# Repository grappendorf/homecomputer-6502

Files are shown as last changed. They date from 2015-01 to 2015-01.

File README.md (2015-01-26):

HomeComputer 6502
=================

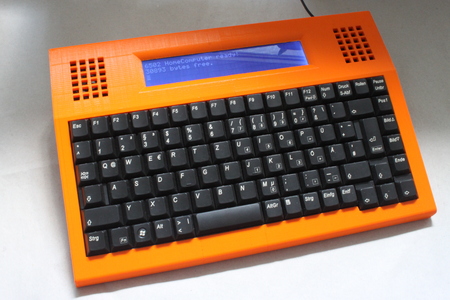
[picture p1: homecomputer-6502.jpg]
HomeComputer 6502


This is my attempt to build a simple, mobile microcomputer system with an 8-bit MOS 6502 CPU that was used in many popular
home computers of the 1970s and 1980s like the Commodore 64 or the Apple II.

The idea was to design a computer like the C64, almost only using parts that were available when this computer was
manufactured.

The hardware is designed with [Eagle](http://www.cadsoft.de/eagle-pcb-design-software/).

The software is written in 6502 assembler and C, with the help of the [CC65 compiler/assembler](http://cc65.github.io/cc65/).

The case is designed with [Autodesk 123D Design](http://www.123dapp.com/design).

Documentation of this project can be found on my website: http://www.grappendorf.net/projects/6502-home-computer

This repositiory contains the following files:

* eagle - Eagle schematic and board files
* schematics - PDF schematics
* case - 123D/STL design files for the case
* firmware - Minimal BASIC interpreter written with CC65,  different versions of the firmware during the development process
* terminal -  Small ruby script for loading/saving of BASIC programs, example BASIC programs

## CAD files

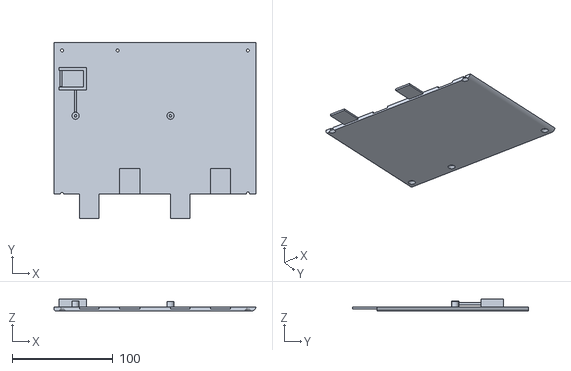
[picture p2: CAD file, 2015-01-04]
case/stl/parts/HomeComputer 6502 Bottom Right.stl
200.0 x 174.5 x 12.0

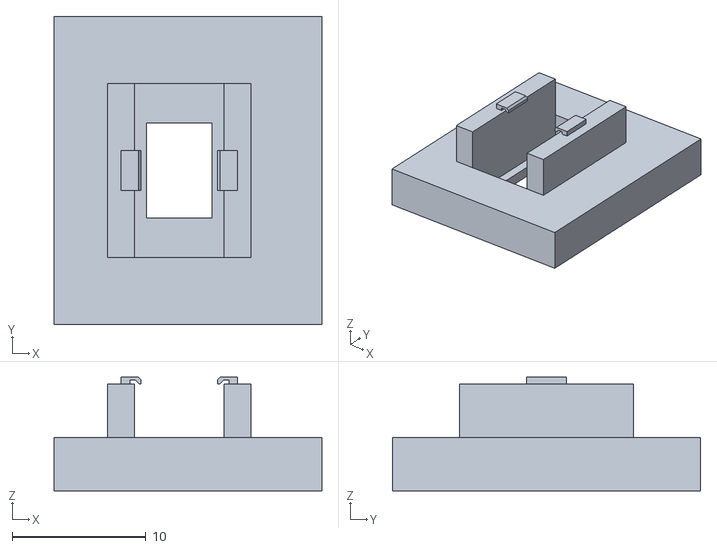
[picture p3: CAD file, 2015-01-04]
case/stl/Switch.stl
20.0 x 23.0 x 8.50

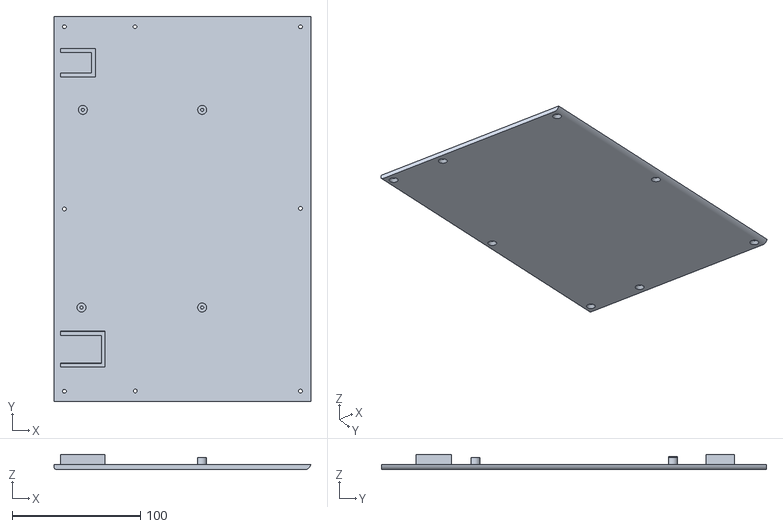
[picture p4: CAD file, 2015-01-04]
case/stl/HomeComputer 6502 Bottom.stl
200.0 x 300.0 x 12.0

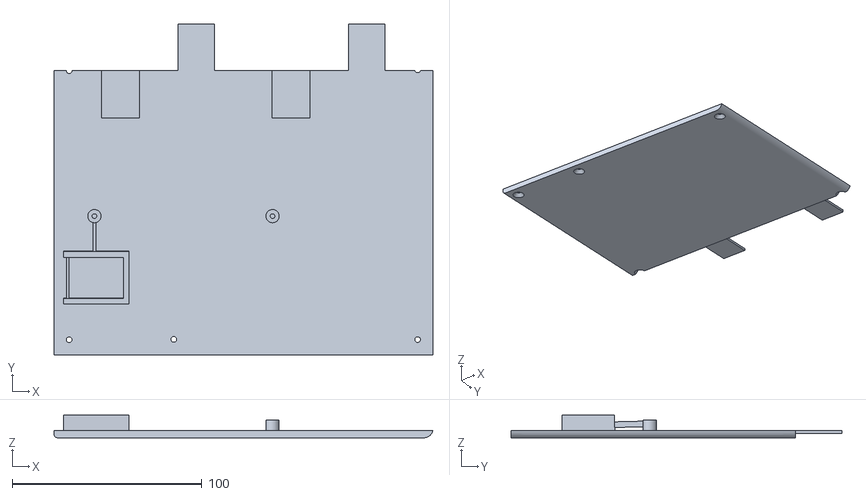
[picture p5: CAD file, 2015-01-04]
case/stl/parts/HomeComputer 6502 Bottom Left.stl
200.0 x 174.6 x 12.0

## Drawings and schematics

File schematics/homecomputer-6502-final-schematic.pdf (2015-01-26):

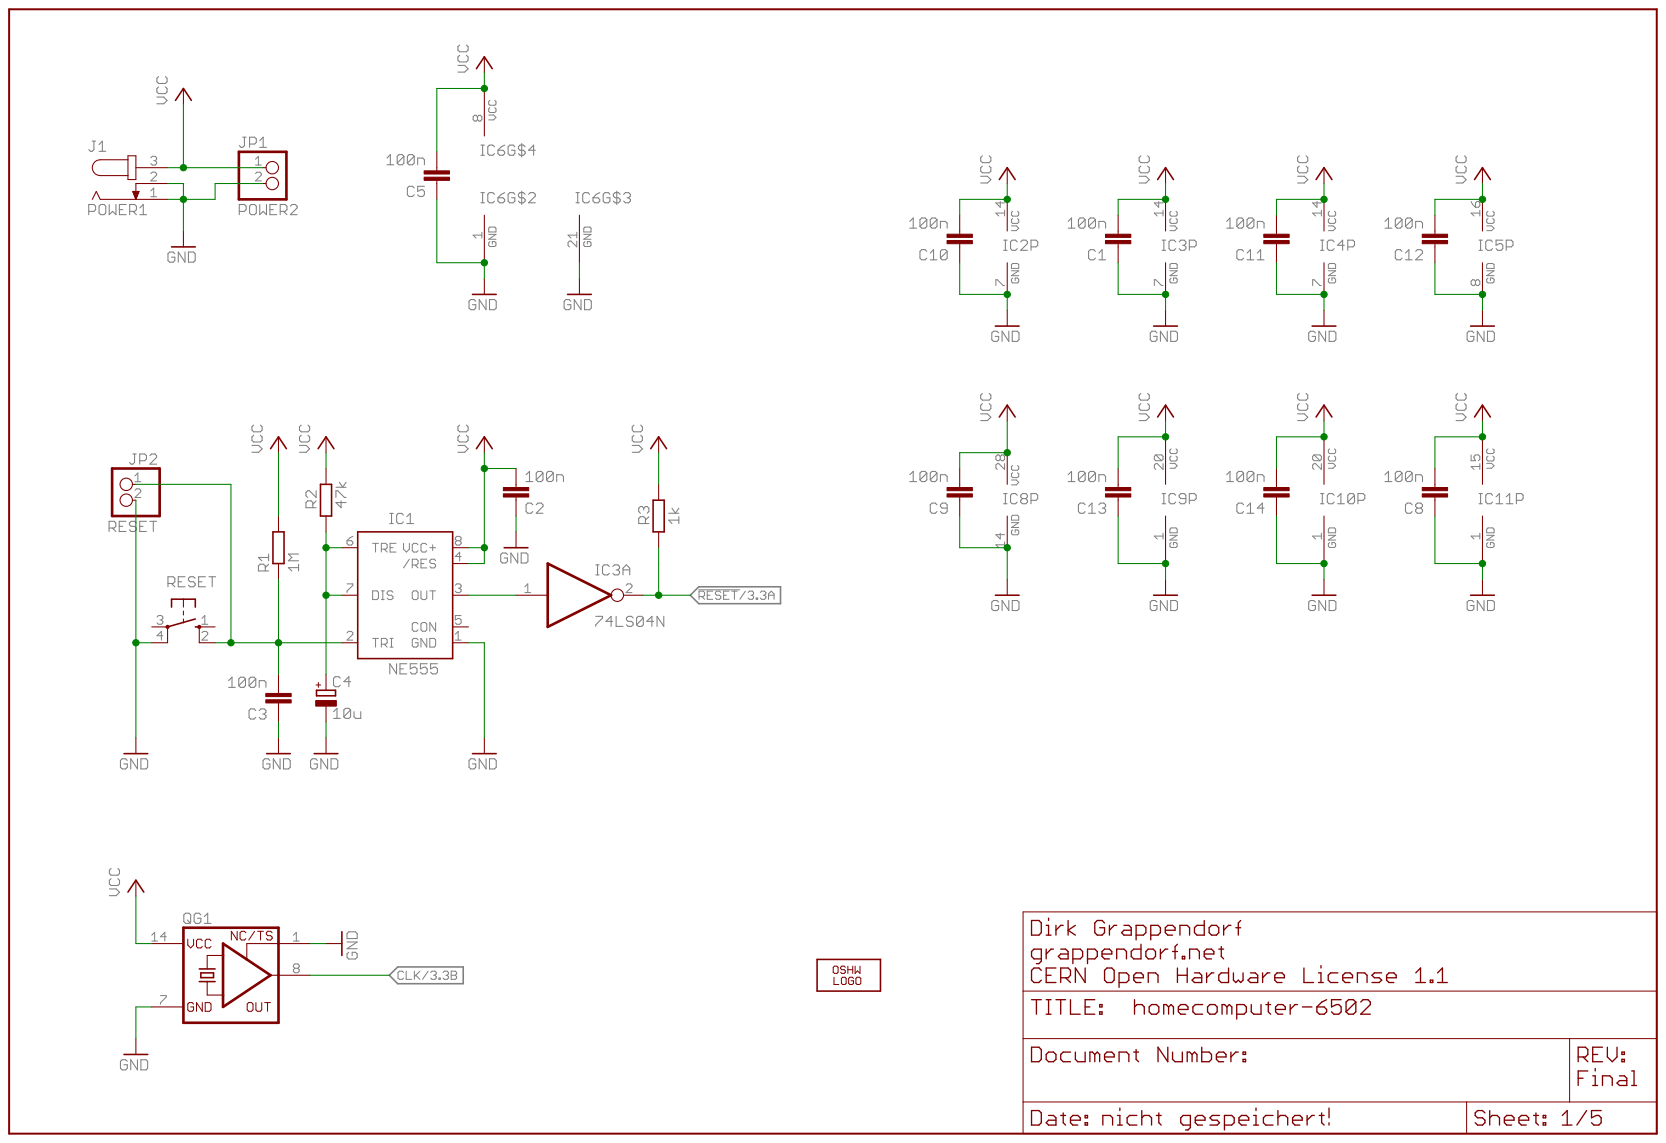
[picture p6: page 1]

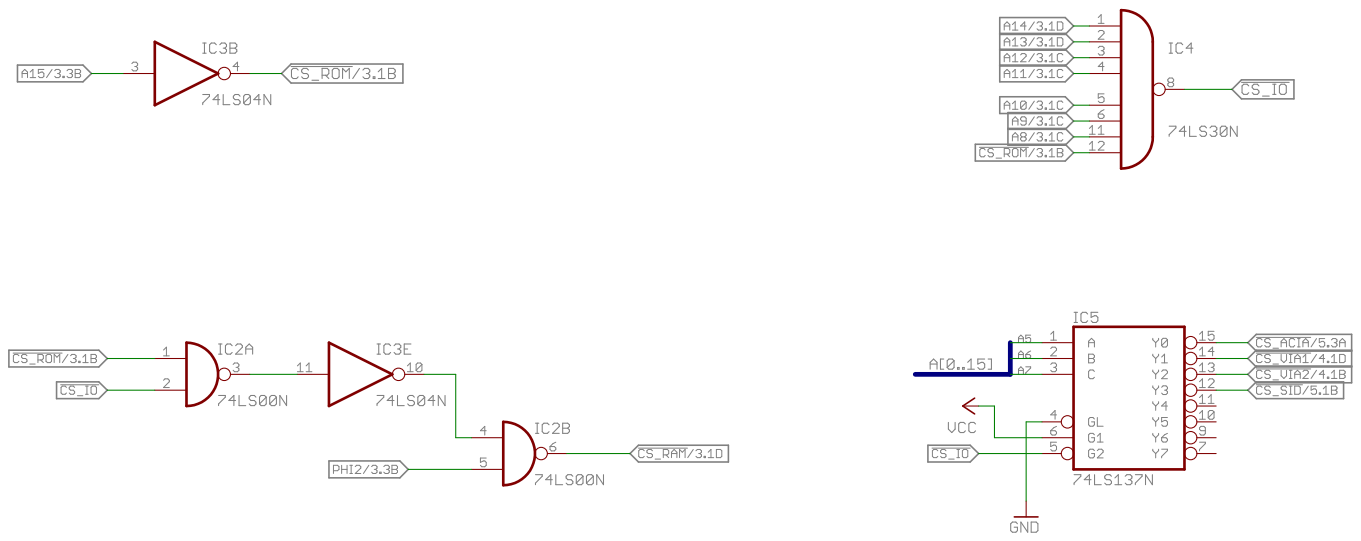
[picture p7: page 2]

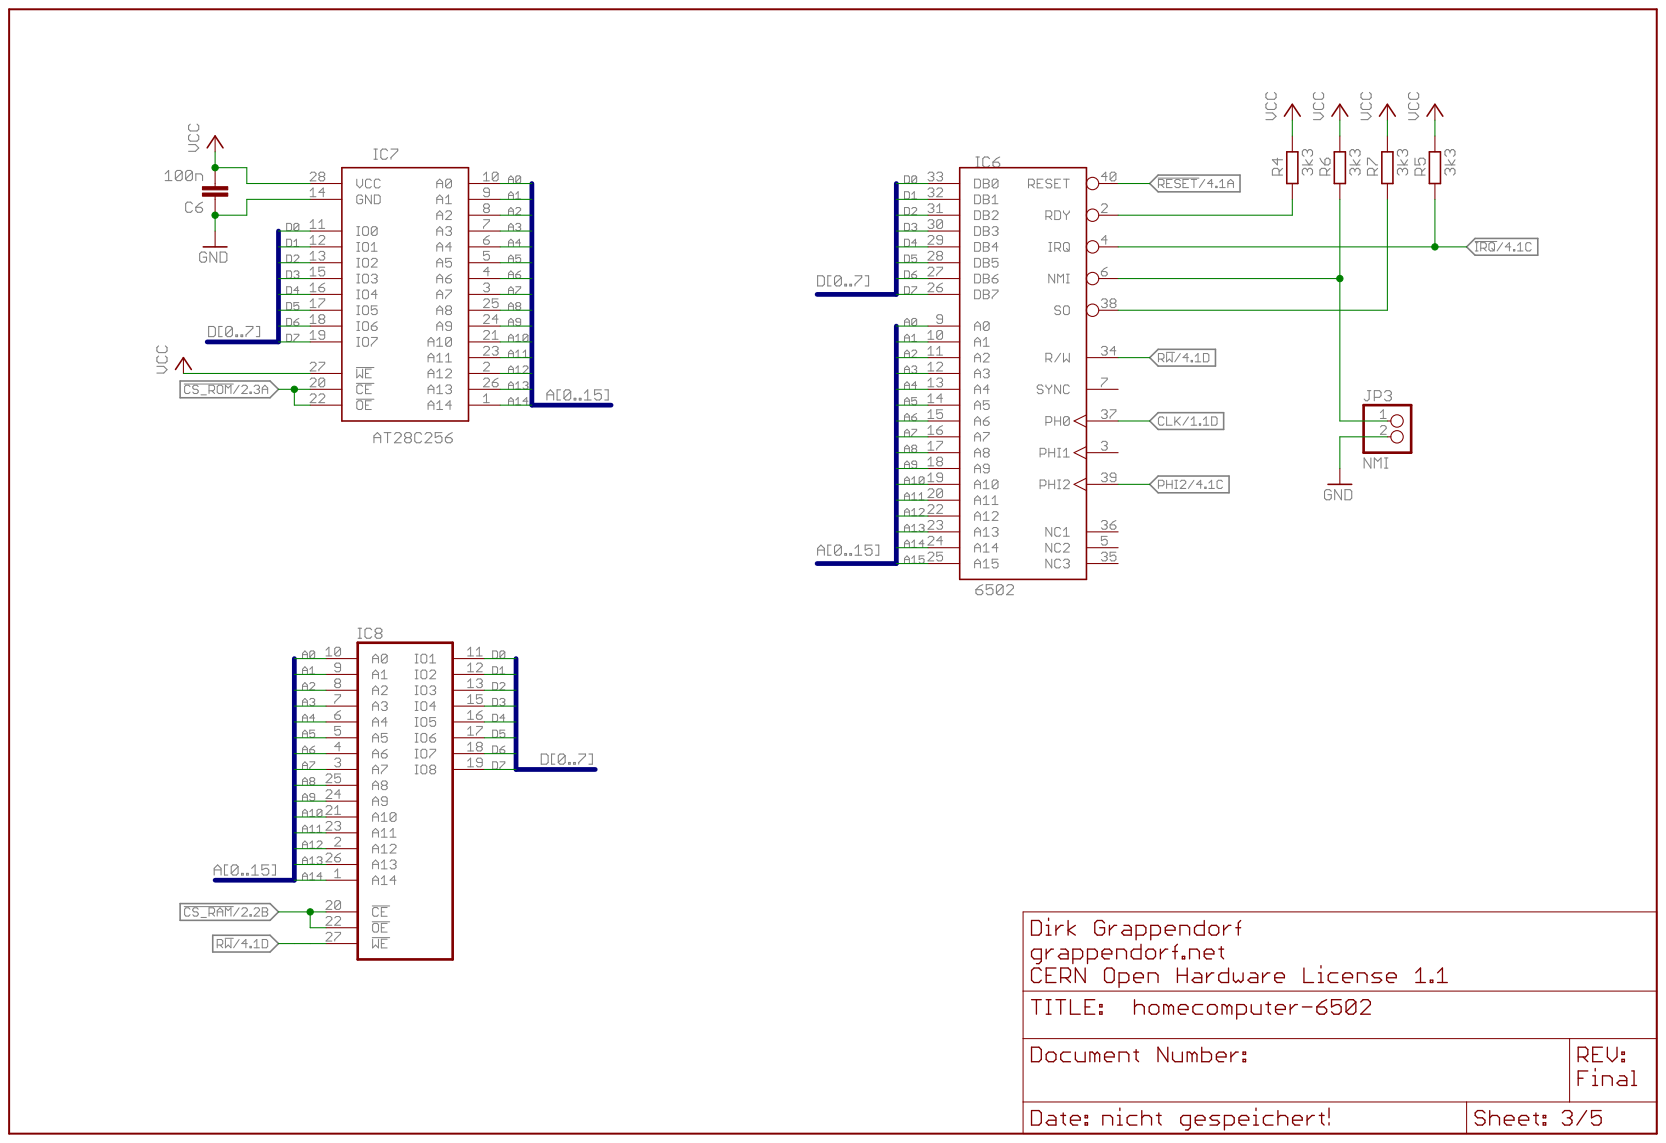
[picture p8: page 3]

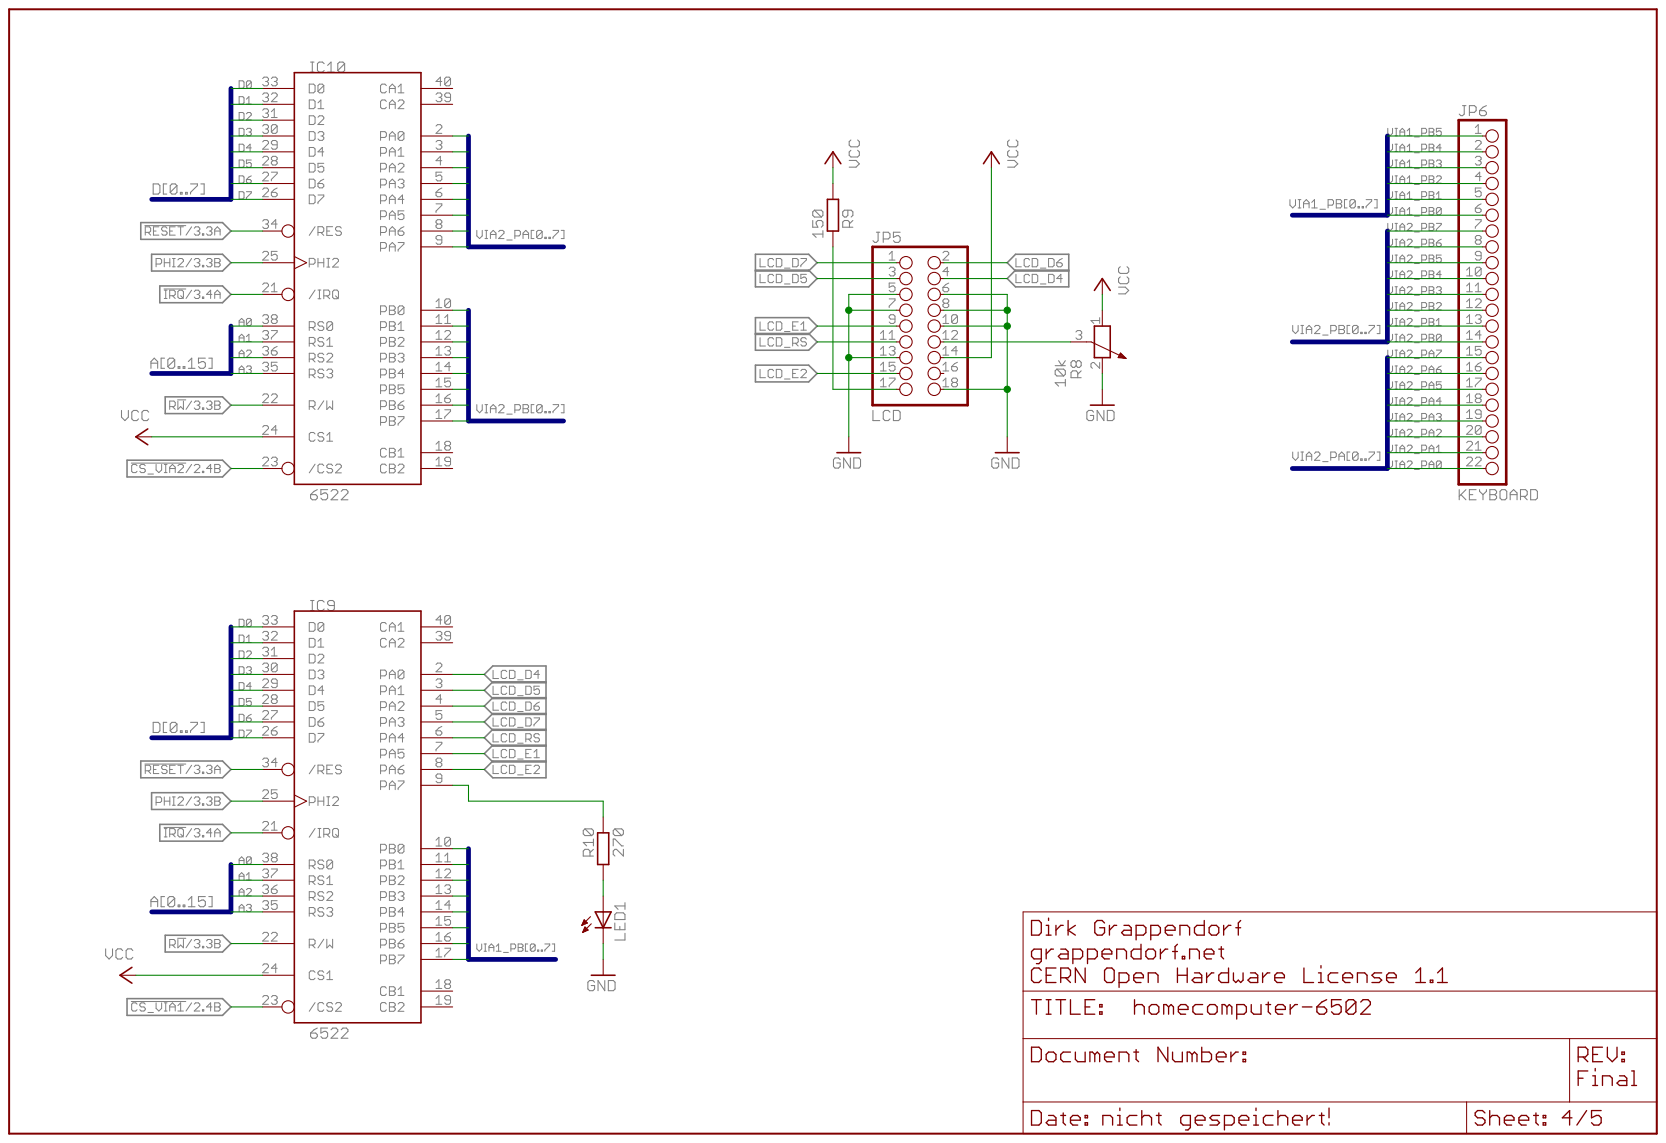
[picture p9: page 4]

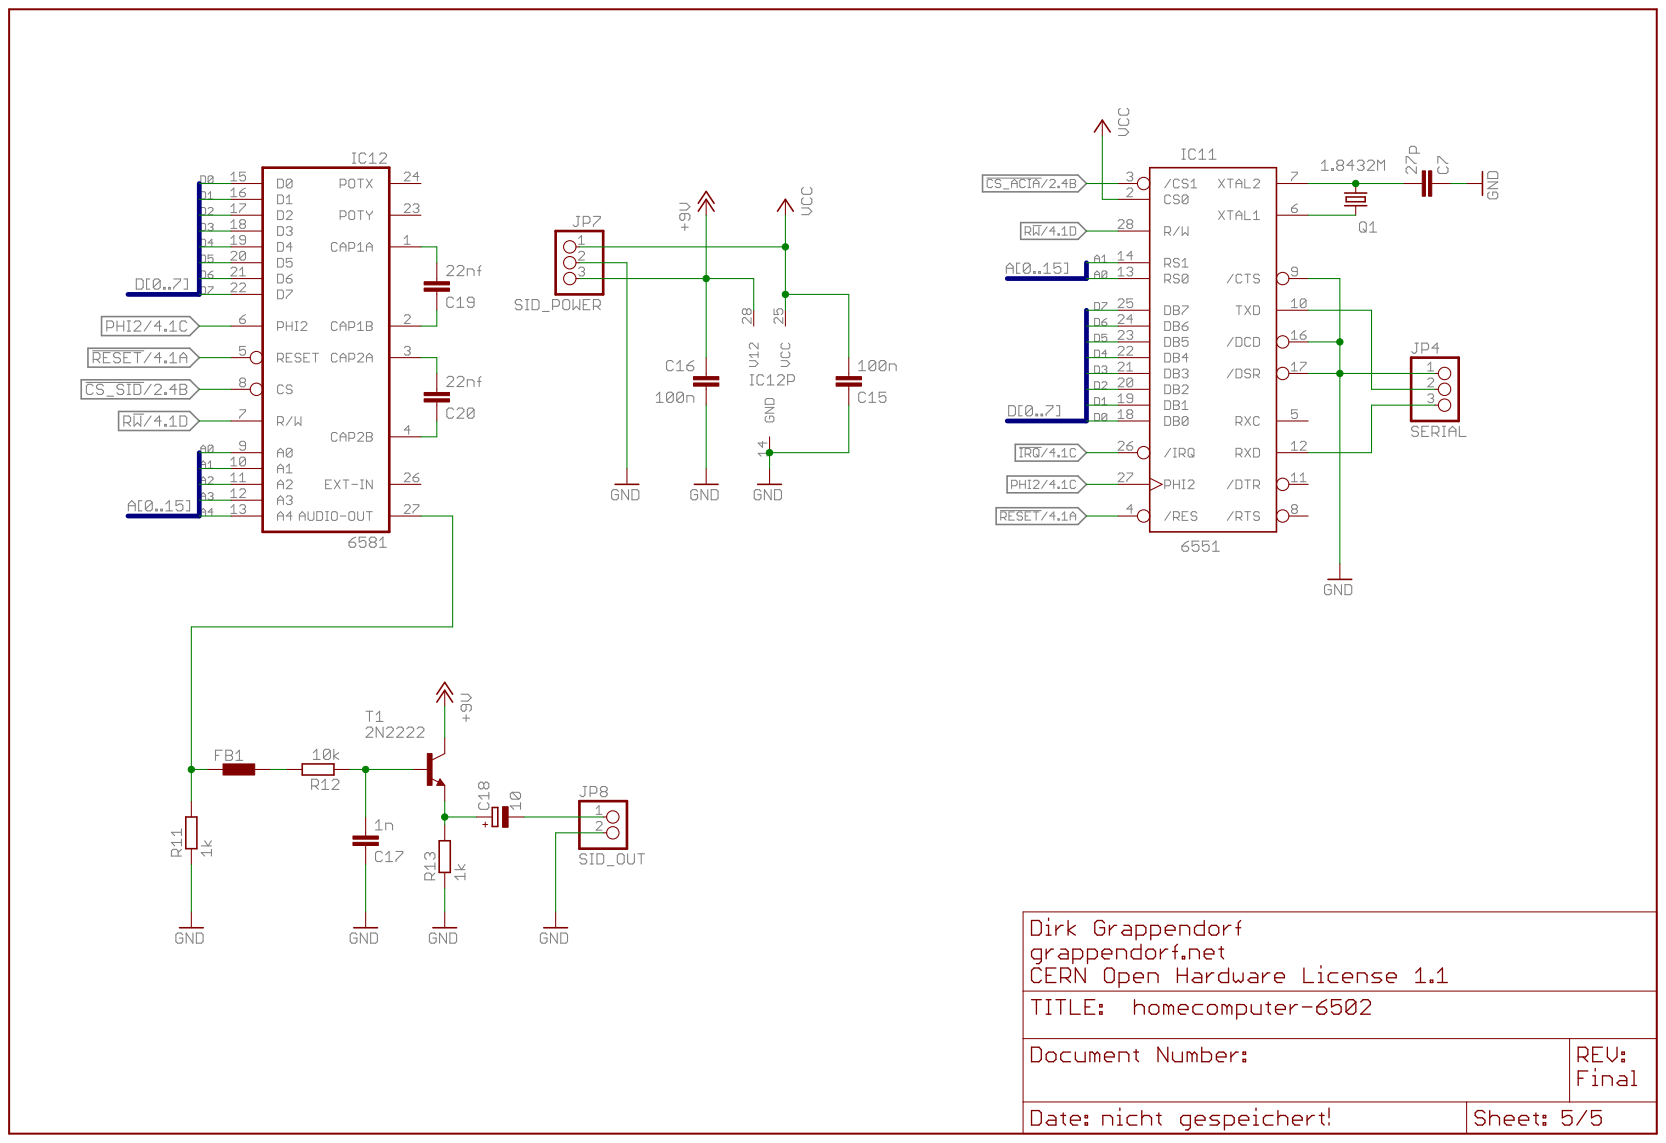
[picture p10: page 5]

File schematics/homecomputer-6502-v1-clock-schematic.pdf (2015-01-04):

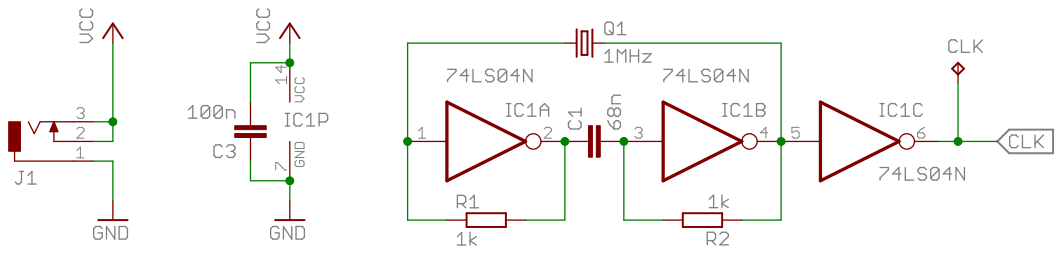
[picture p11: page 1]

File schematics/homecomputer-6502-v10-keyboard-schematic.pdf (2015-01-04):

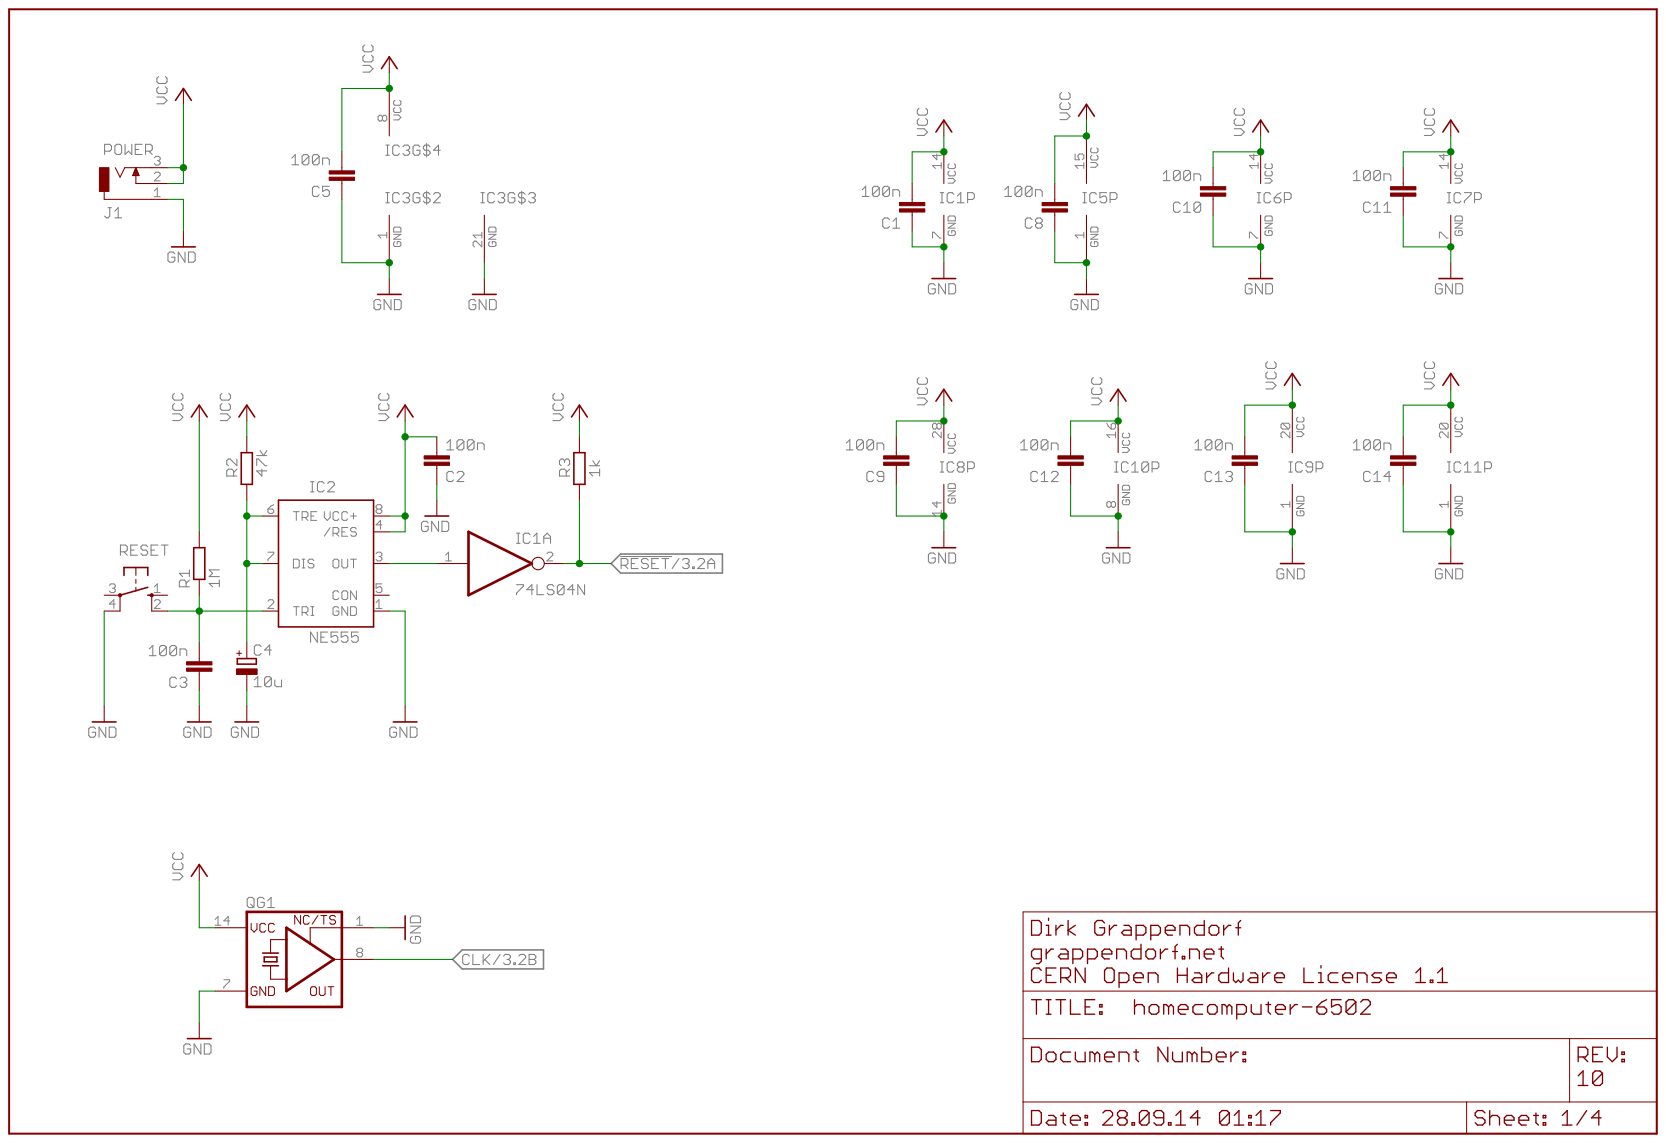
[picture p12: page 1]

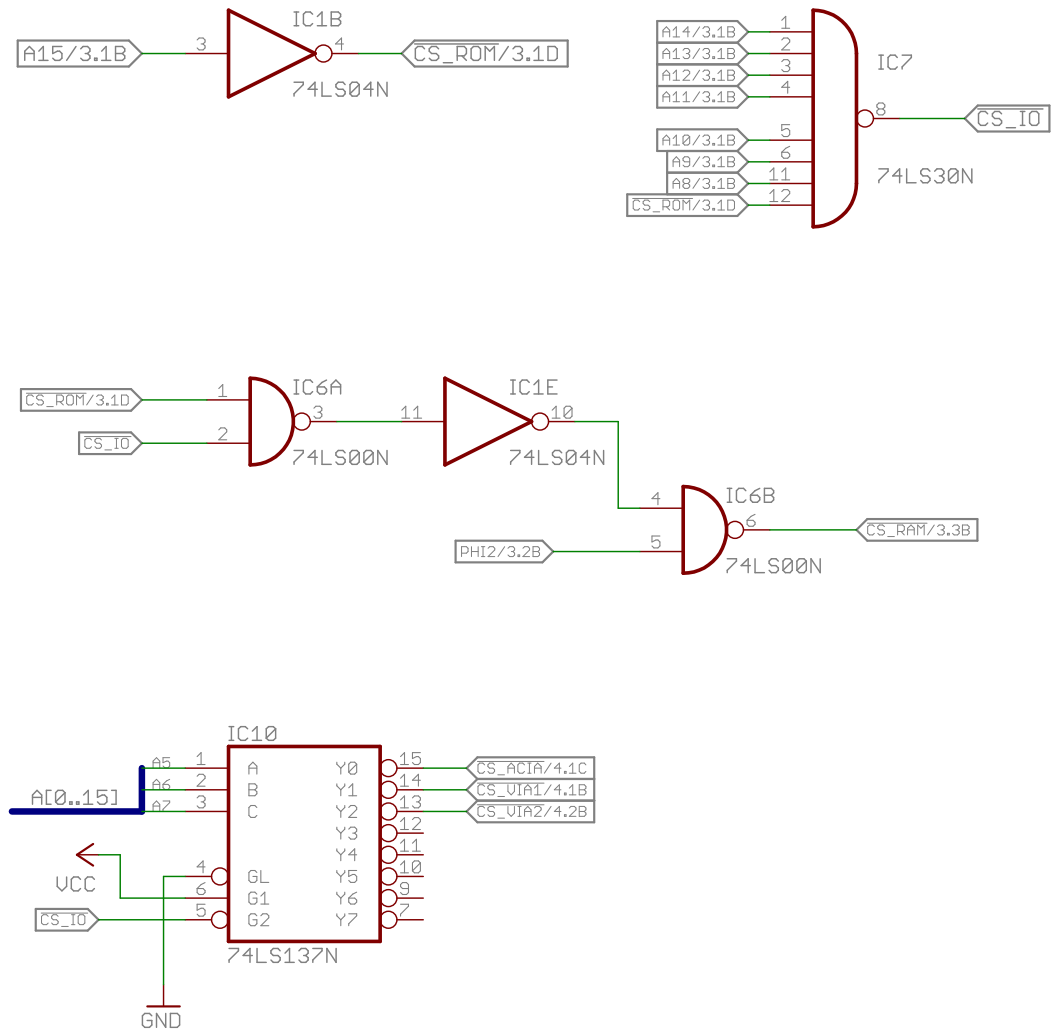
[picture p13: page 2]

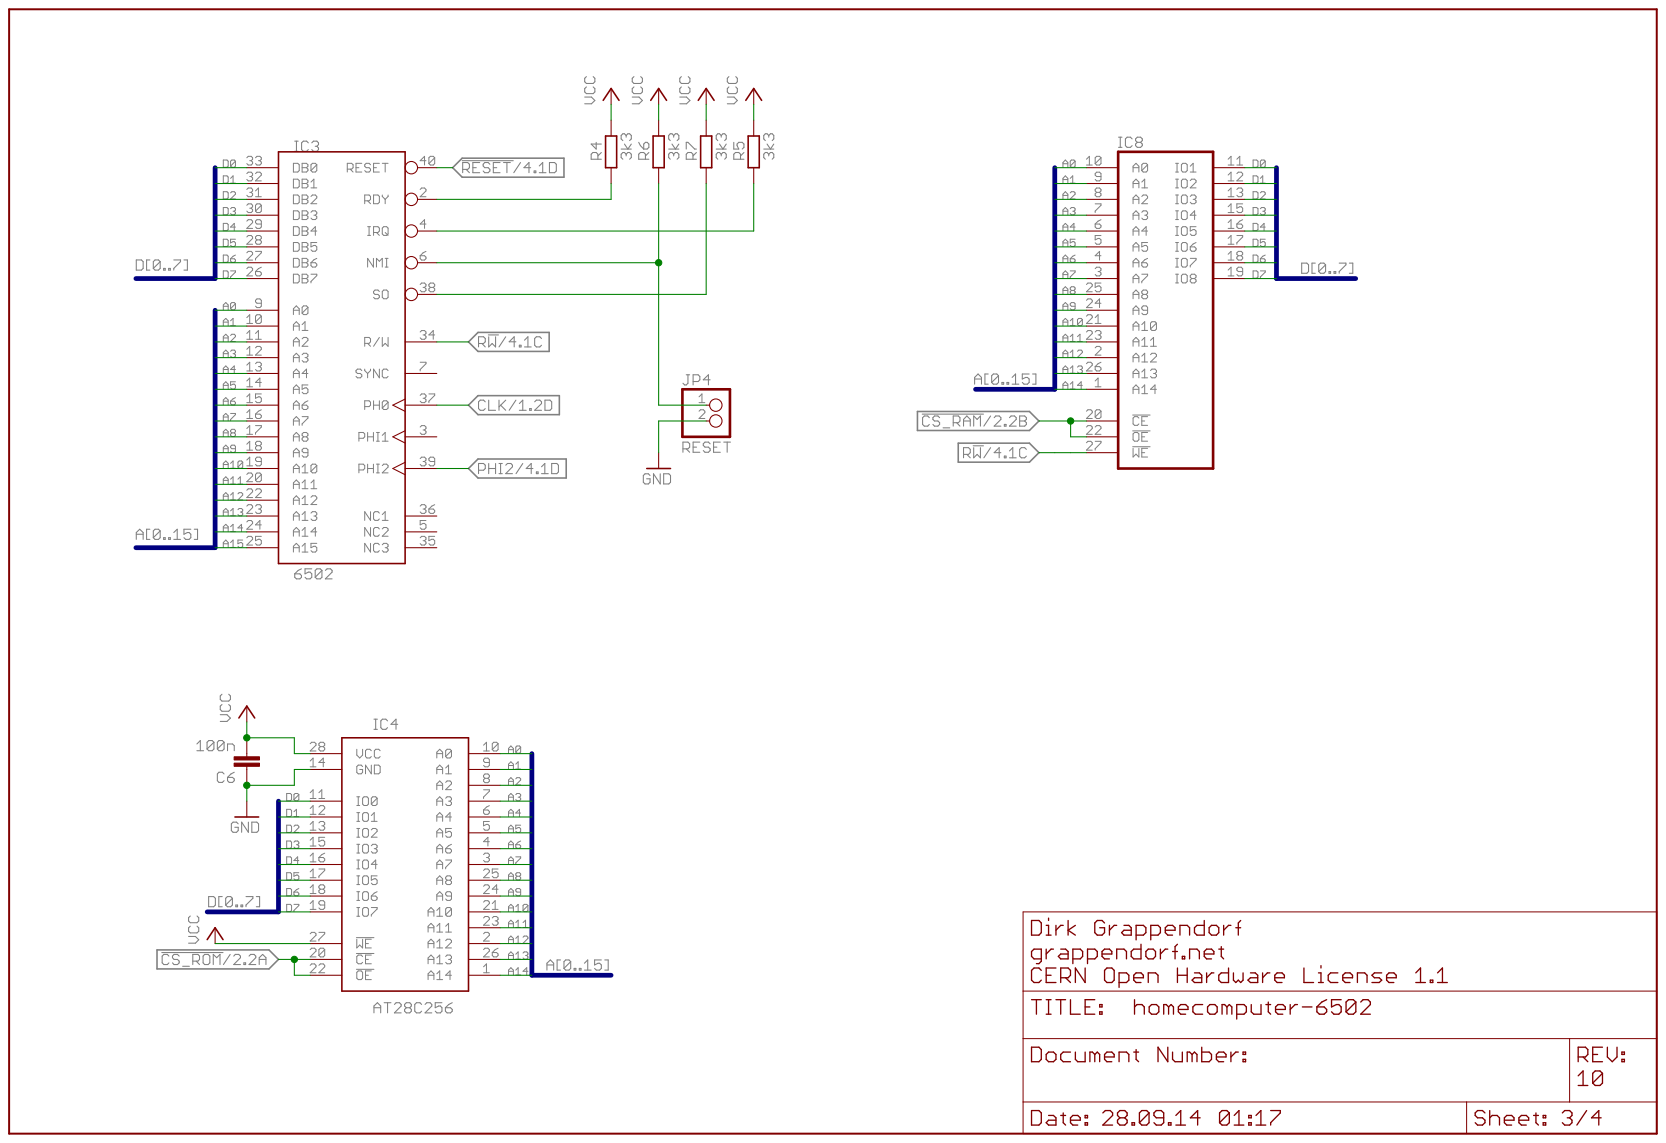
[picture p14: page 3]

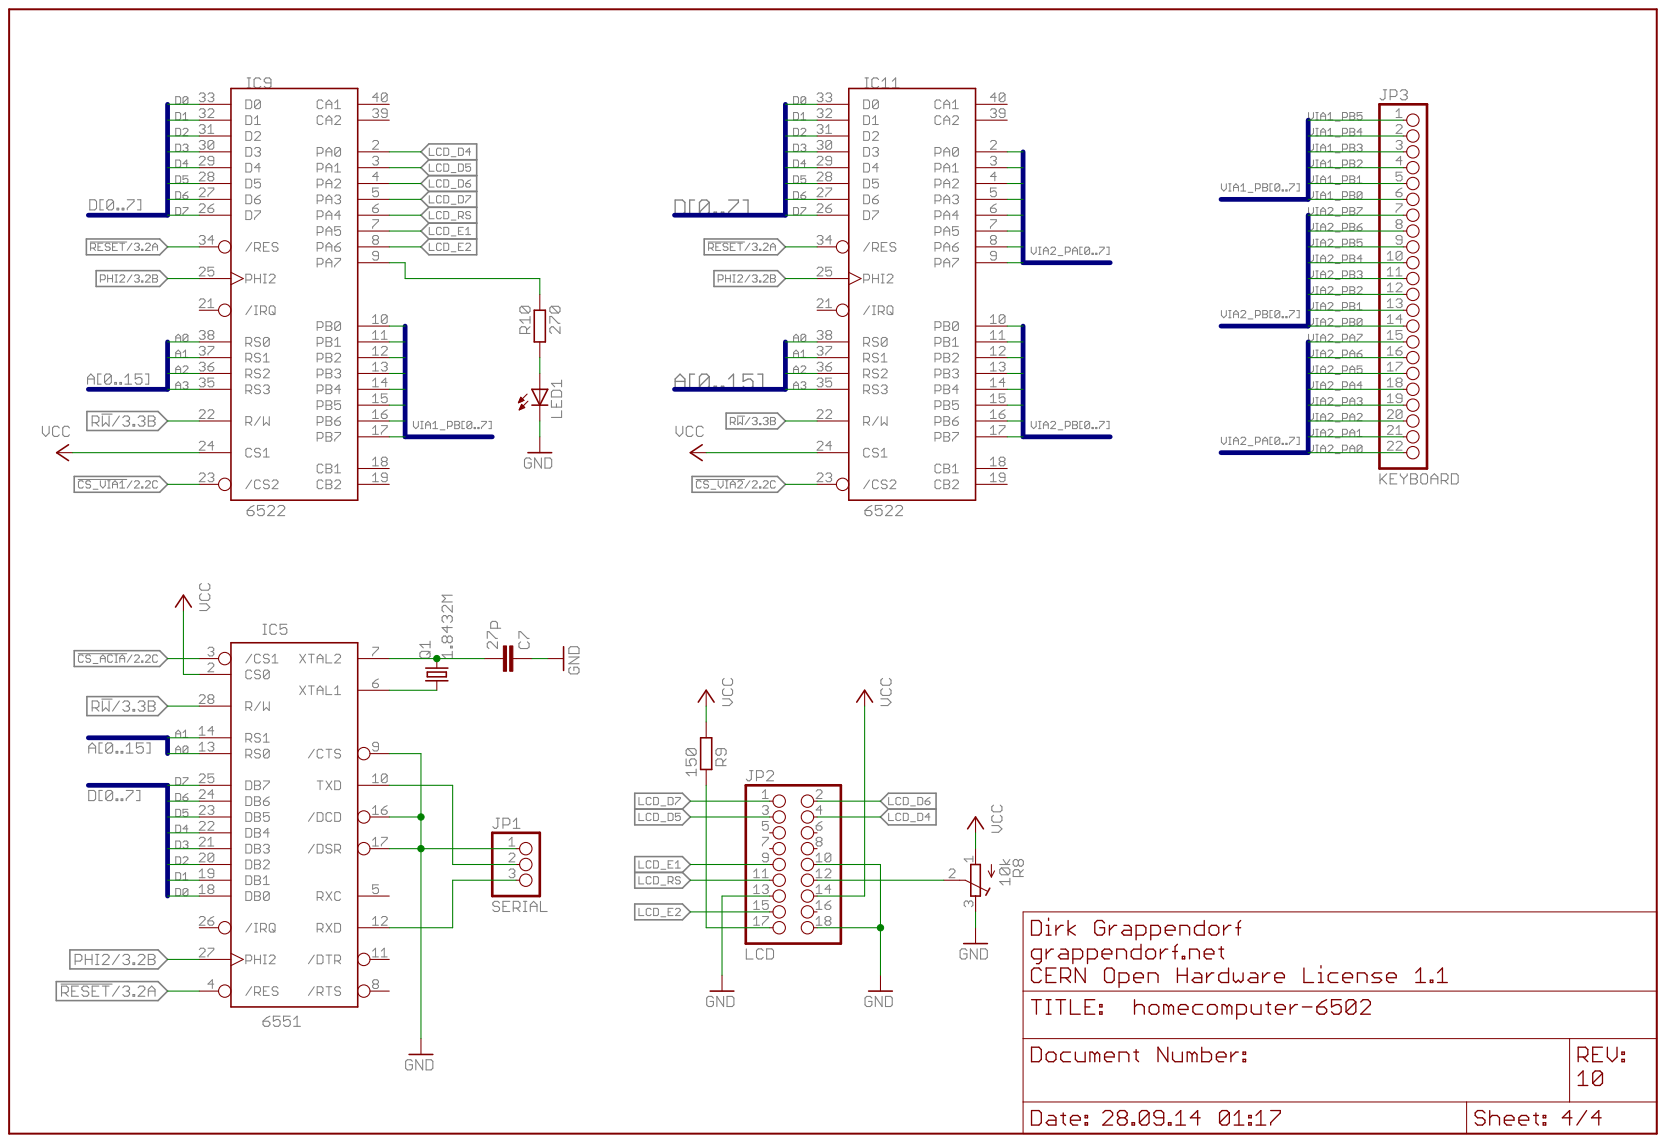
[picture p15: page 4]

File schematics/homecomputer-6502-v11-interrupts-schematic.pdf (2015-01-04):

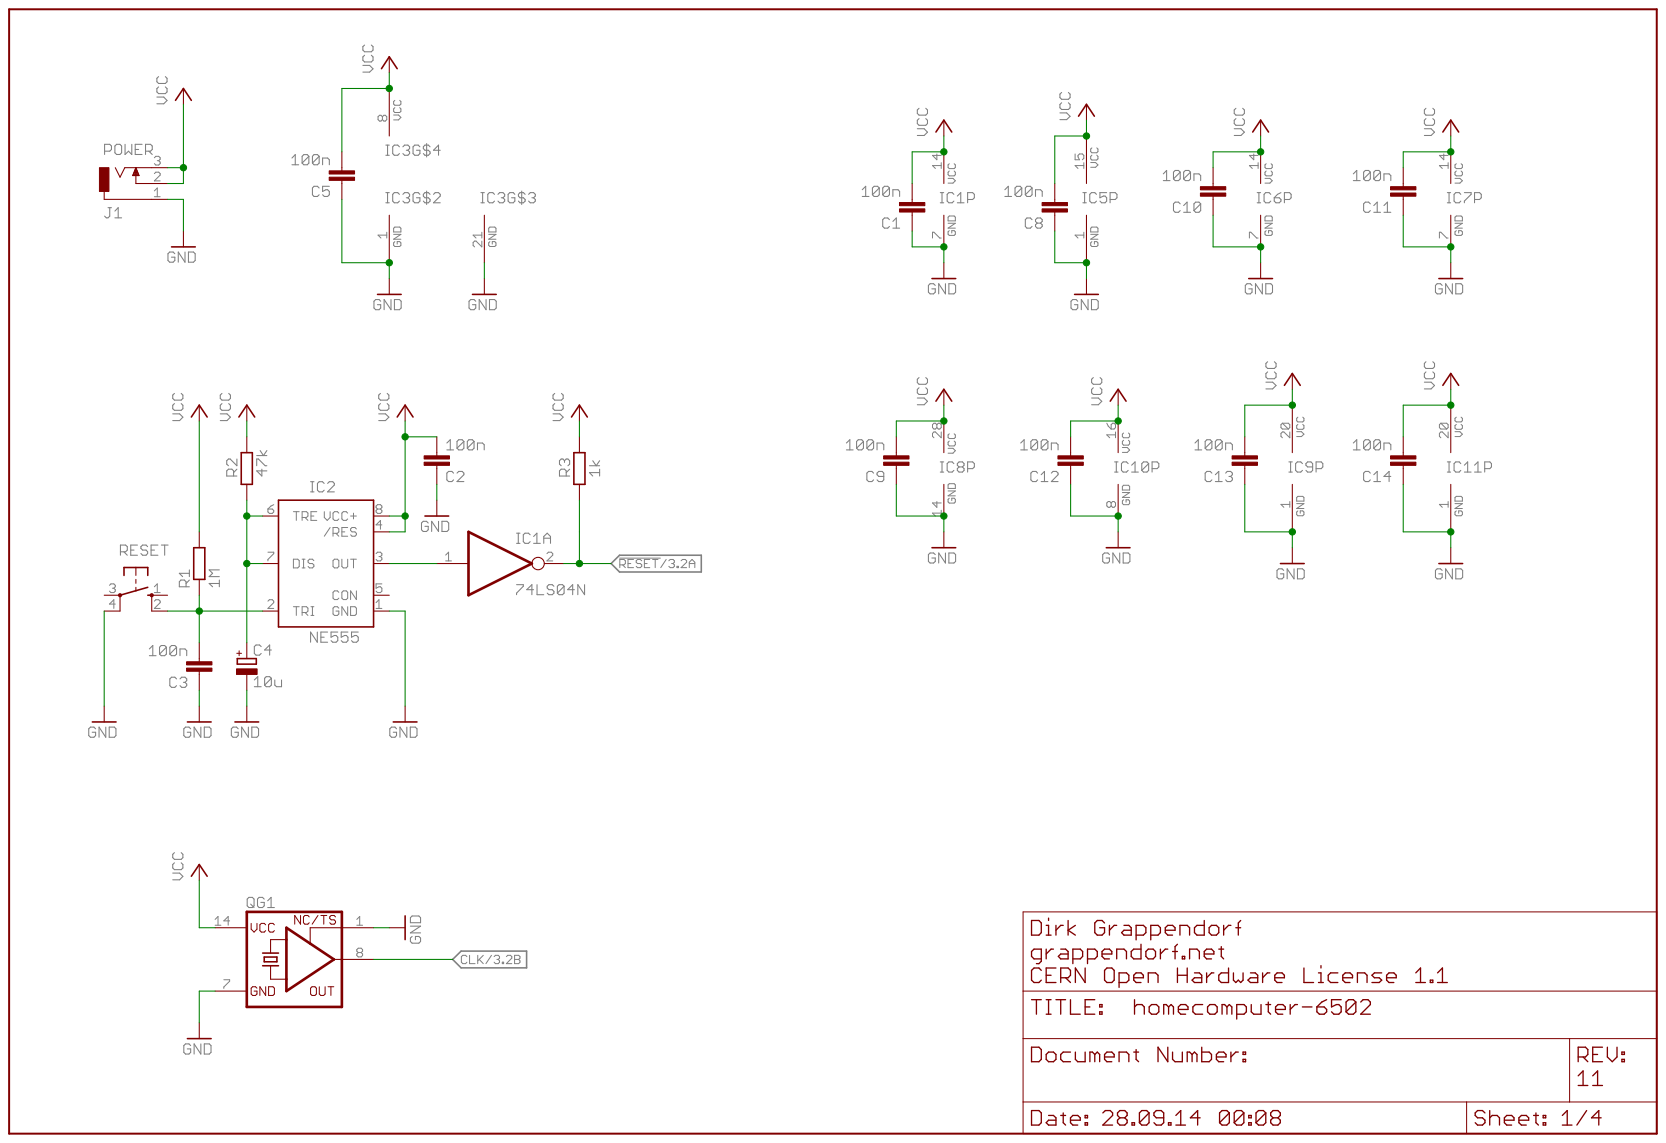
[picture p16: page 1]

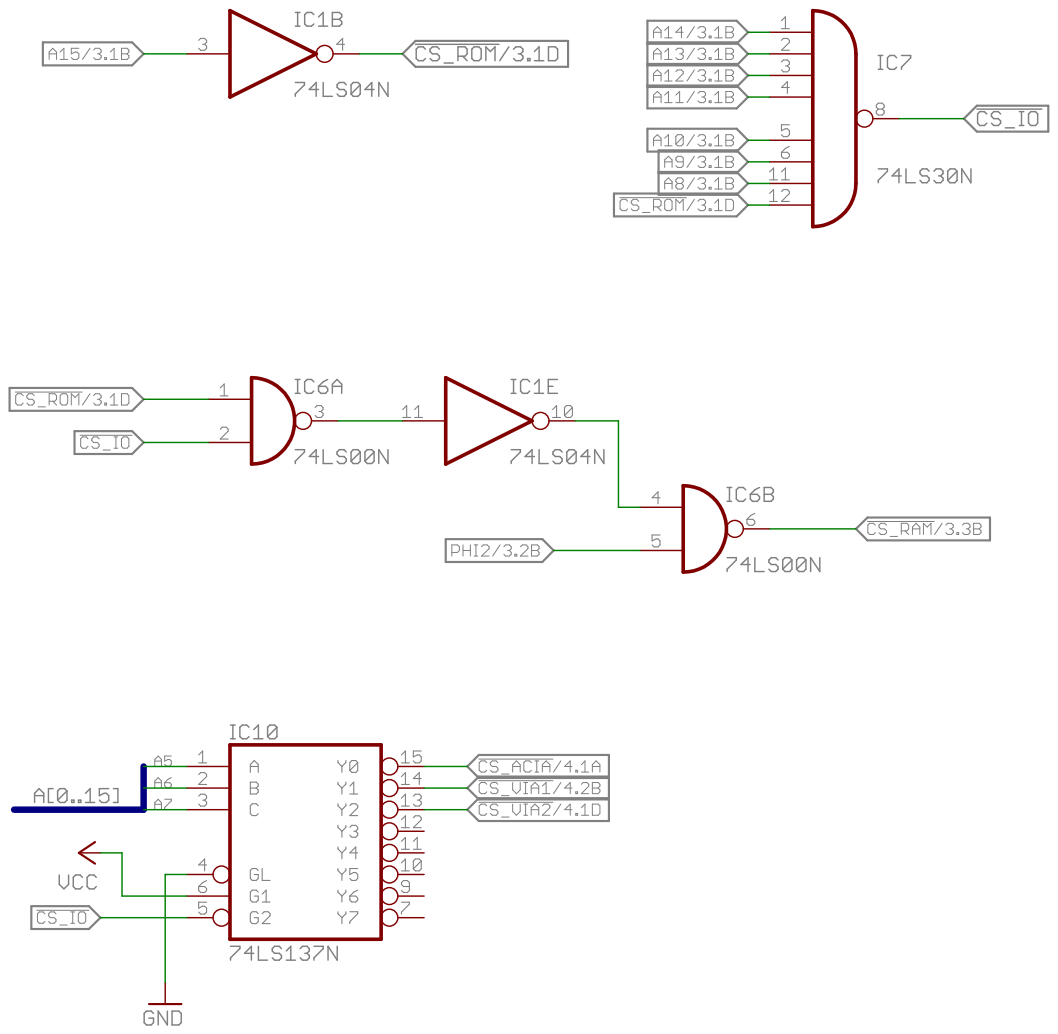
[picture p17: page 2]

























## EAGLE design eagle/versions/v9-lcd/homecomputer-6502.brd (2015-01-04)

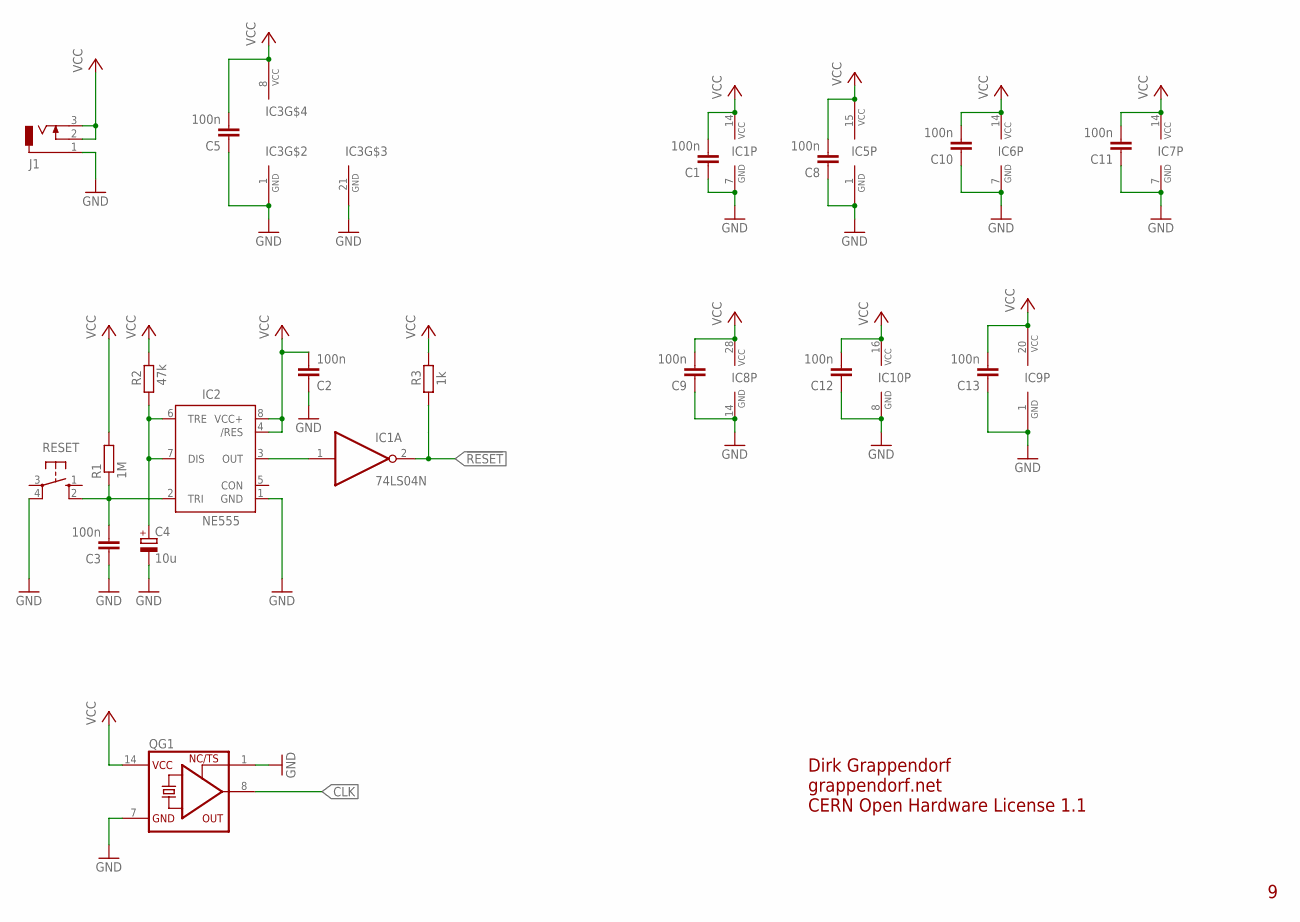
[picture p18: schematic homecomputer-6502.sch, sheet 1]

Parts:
C1, C2, C3, C5, C8, C9, C10, C11, C12, C13: 100n; C025-024X044
C4: 10u; E2,5-6E
IC1: 74LS04N; DIL14
IC2: NE555; DIL-08
IC3: 6502; DIP40
IC5: 6551; DIP28
IC6: 74LS00N; DIL14
IC7: 74LS30N; DIL14
IC8: 61256; DIL28-3
IC9: 6522; DIP40
IC10: 74LS137N; DIL16
J1: DCJ0303
QG1: XO-14; DIL14S
R1: 1M; 0204/5
R2: 47k; 0204/5
R3: 1k; 0204/5
RESET: 10-XX; B3F-10XX

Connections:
!RESET: IC1.2 (O), R3.1; also elsewhere on the board
CLK: QG1.8 (OUT); also elsewhere on the board
GND: C1.1, C2.1, C3.1, C4.-, C5.1, C8.1, C9.1, C10.1, C11.1, C12.1, C13.1, IC1.7 (GND), IC2.1 (GND), IC3.1 (GND), IC3.21 (GND), IC5.1 (GND), IC6.7 (GND), IC7.7 (GND), IC8.14 (GND), IC9.1 (GND), IC10.8 (GND), J1.1, QG1.1 (TS), QG1.7 (GND), RESET.4 (P1); also elsewhere on the board
unnamed: C4.+, IC2.6 (TRE), IC2.7 (DIS), R2.1
unnamed: IC1.1 (I), IC2.3 (OUT)
unnamed: C3.2, IC2.2 (TRI), R1.1, RESET.2 (S1)
VCC: C1.2, C2.2, C5.2, C8.2, C9.2, C10.2, C11.2, C12.2, C13.2, IC1.14 (VCC), IC2.4 (/RES), IC2.8 (VCC+), IC3.8 (VCC), IC5.15 (VCC), IC6.14 (VCC), IC7.14 (VCC), IC8.28 (VCC), IC9.20 (VCC), IC10.16 (VCC), J1.2, J1.3, QG1.14 (VCC), R1.2, R2.2, R3.2; also elsewhere on the board

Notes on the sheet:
Dirk Grappendorf
grappendorf.net
CERN Open Hardware License 1.1

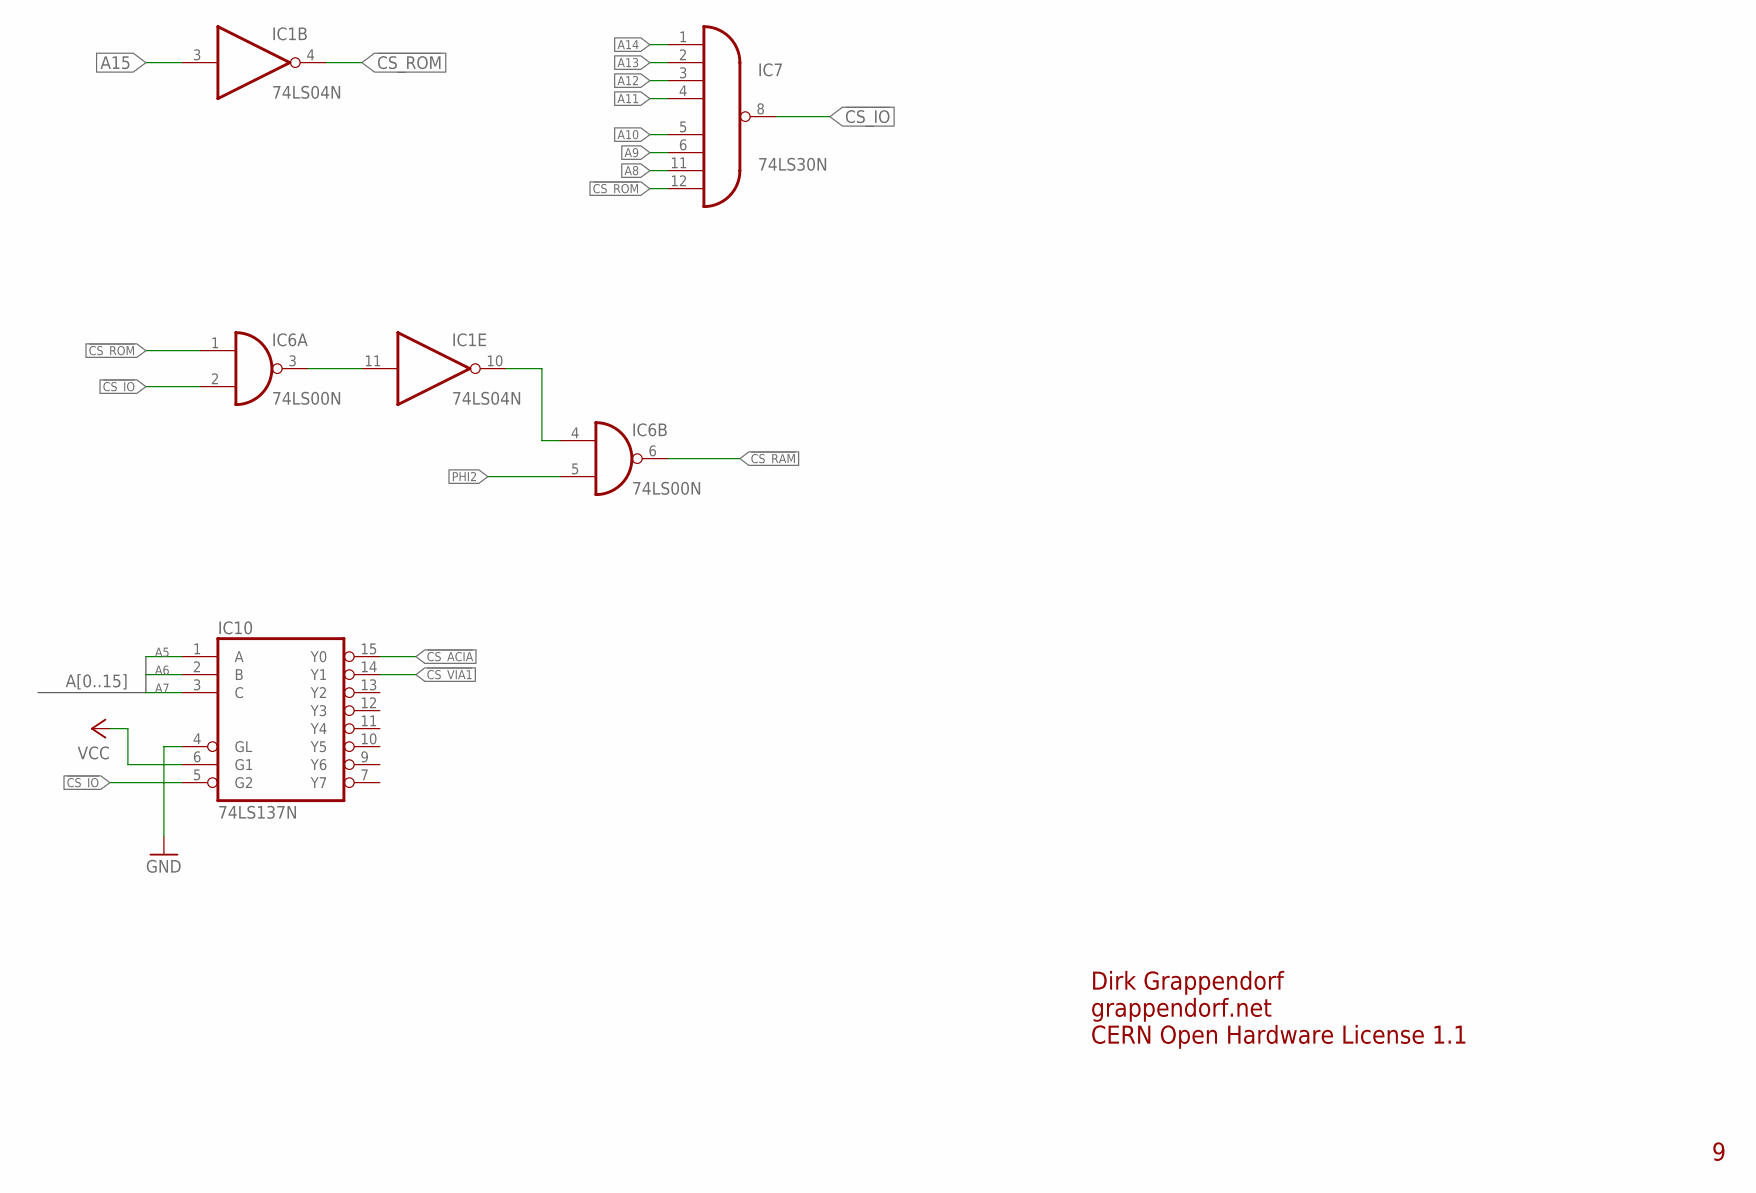
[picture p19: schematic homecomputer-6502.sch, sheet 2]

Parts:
IC1: 74LS04N; DIL14
IC6: 74LS00N; DIL14
IC7: 74LS30N; DIL14
IC10: 74LS137N; DIL16

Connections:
!CS_ACIA: IC10.15 (Y0); also elsewhere on the board
!CS_IO: IC6.2 (I1), IC7.8 (O), IC10.5 (G2)
!CS_RAM: IC6.6 (O); also elsewhere on the board
!CS_ROM: IC1.4 (O), IC6.1 (I0), IC7.12 (I7); also elsewhere on the board
!CS_VIA1: IC10.14 (Y1); also elsewhere on the board
A5: IC10.1 (A); also elsewhere on the board
A6: IC10.2 (B); also elsewhere on the board
A7: IC10.3 (C); also elsewhere on the board
A8: IC7.11 (I6); also elsewhere on the board
A9: IC7.6 (I5); also elsewhere on the board
A10: IC7.5 (I4); also elsewhere on the board
A11: IC7.4 (I3); also elsewhere on the board
A12: IC7.3 (I2); also elsewhere on the board
A13: IC7.2 (I1); also elsewhere on the board
A14: IC7.1 (I0); also elsewhere on the board
A15: IC1.3 (I); also elsewhere on the board
GND: IC10.4 (GL); also elsewhere on the board
unnamed: IC1.11 (I), IC6.3 (O)
unnamed: IC1.10 (O), IC6.4 (I0)
PHI2: IC6.5 (I1); also elsewhere on the board
VCC: IC10.6 (G1); also elsewhere on the board

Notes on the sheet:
Dirk Grappendorf
grappendorf.net
CERN Open Hardware License 1.1

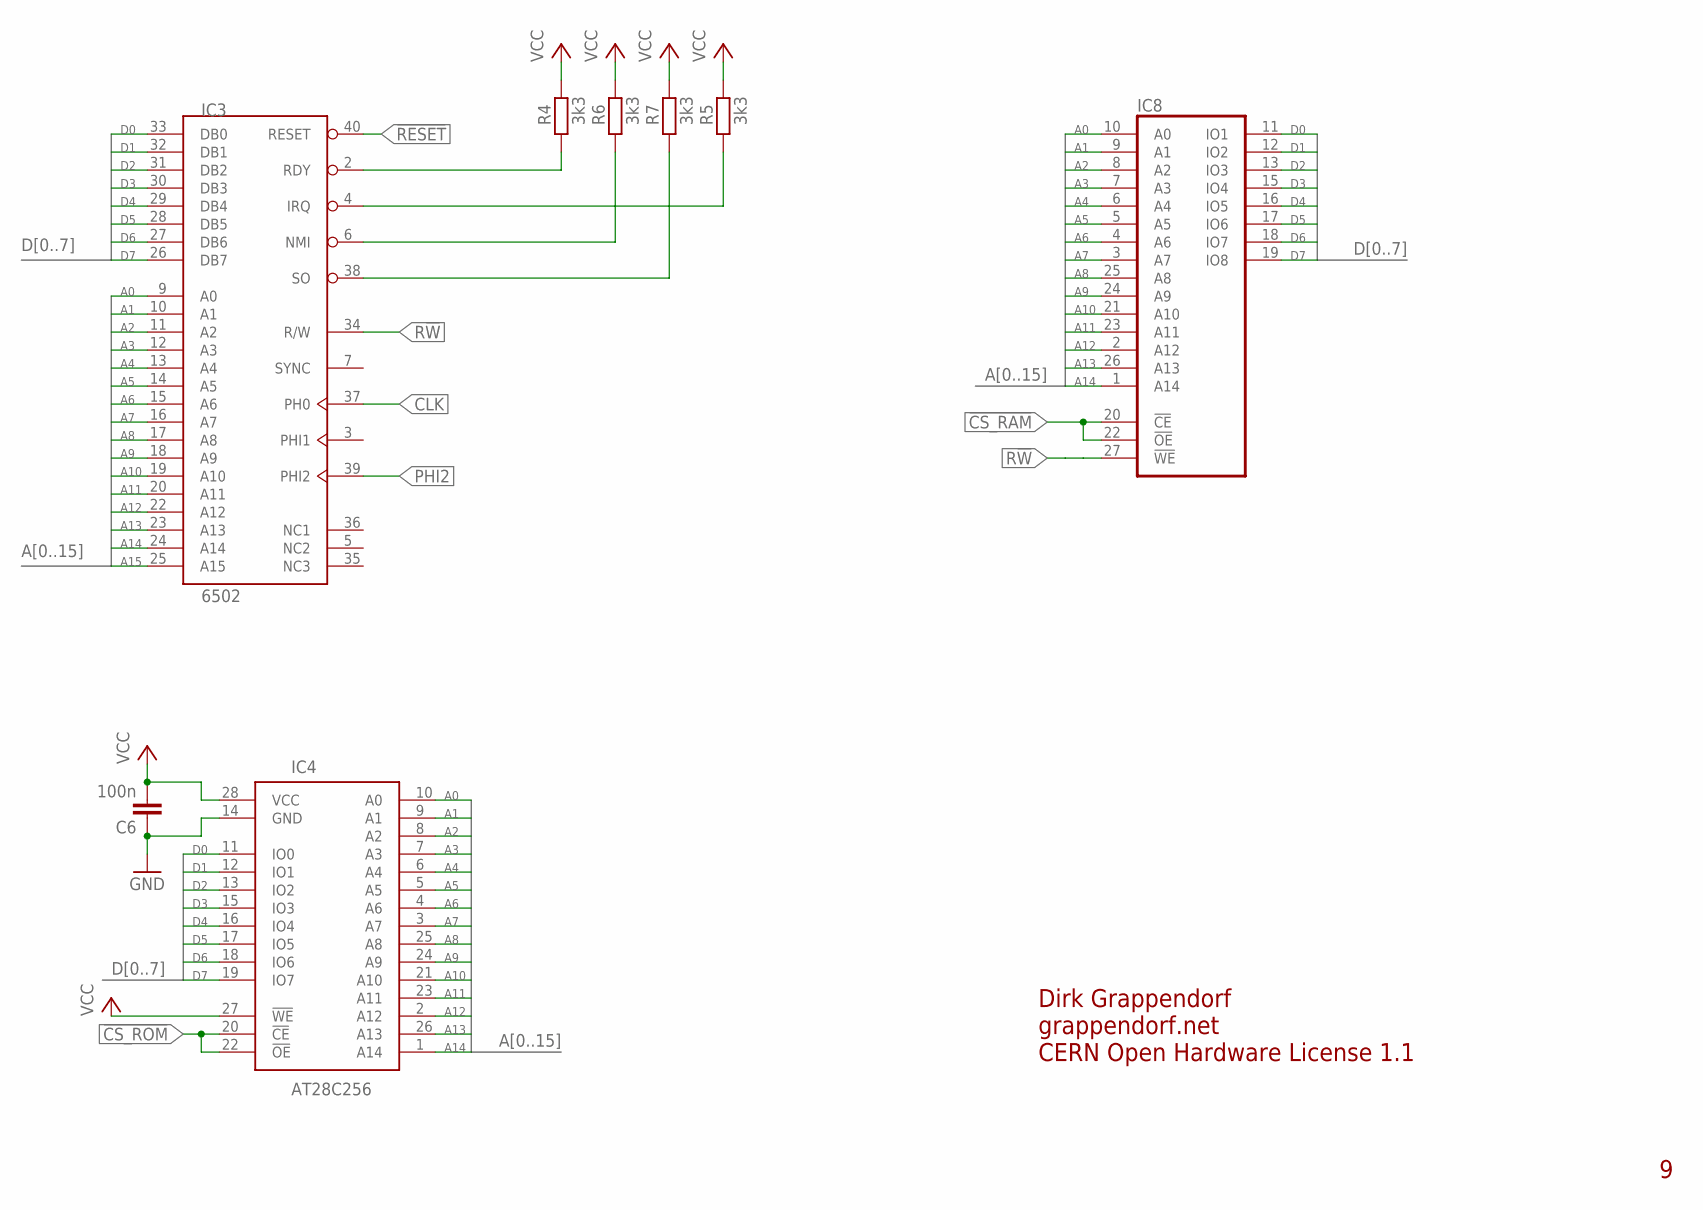
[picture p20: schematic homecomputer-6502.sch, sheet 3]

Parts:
C6: 100n; C025-024X044
IC3: 6502; DIP40
IC4: AT28C256; DIL28-6
IC8: 61256; DIL28-3
R4, R5, R6, R7: 3k3; 0204/5

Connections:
!CS_RAM: IC8.20 (!CE), IC8.22 (!OE); also elsewhere on the board
!CS_ROM: IC4.20 (!CE), IC4.22 (!OE); also elsewhere on the board
!IRQ: IC3.4 (IRQ), R5.1
!RESET: IC3.40 (RESET); also elsewhere on the board
A0: IC3.9 (A0), IC4.10 (A0), IC8.10 (A0); also elsewhere on the board
A1: IC3.10 (A1), IC4.9 (A1), IC8.9 (A1); also elsewhere on the board
A2: IC3.11 (A2), IC4.8 (A2), IC8.8 (A2); also elsewhere on the board
A3: IC3.12 (A3), IC4.7 (A3), IC8.7 (A3); also elsewhere on the board
A4: IC3.13 (A4), IC4.6 (A4), IC8.6 (A4)
A5: IC3.14 (A5), IC4.5 (A5), IC8.5 (A5); also elsewhere on the board
A6: IC3.15 (A6), IC4.4 (A6), IC8.4 (A6); also elsewhere on the board
A7: IC3.16 (A7), IC4.3 (A7), IC8.3 (A7); also elsewhere on the board
A8: IC3.17 (A8), IC4.25 (A8), IC8.25 (A8); also elsewhere on the board
A9: IC3.18 (A9), IC4.24 (A9), IC8.24 (A9); also elsewhere on the board
A10: IC3.19 (A10), IC4.21 (A10), IC8.21 (A10); also elsewhere on the board
A11: IC3.20 (A11), IC4.23 (A11), IC8.23 (A11); also elsewhere on the board
A12: IC3.22 (A12), IC4.2 (A12), IC8.2 (A12); also elsewhere on the board
A13: IC3.23 (A13), IC4.26 (A13), IC8.26 (A13); also elsewhere on the board
A14: IC3.24 (A14), IC4.1 (A14), IC8.1 (A14); also elsewhere on the board
A15: IC3.25 (A15); also elsewhere on the board
CLK: IC3.37 (PH0); also elsewhere on the board
D0: IC3.33 (DB0), IC4.11 (IO0), IC8.11 (IO1); also elsewhere on the board
D1: IC3.32 (DB1), IC4.12 (IO1), IC8.12 (IO2); also elsewhere on the board
D2: IC3.31 (DB2), IC4.13 (IO2), IC8.13 (IO3); also elsewhere on the board
D3: IC3.30 (DB3), IC4.15 (IO3), IC8.15 (IO4); also elsewhere on the board
D4: IC3.29 (DB4), IC4.16 (IO4), IC8.16 (IO5); also elsewhere on the board
D5: IC3.28 (DB5), IC4.17 (IO5), IC8.17 (IO6); also elsewhere on the board
D6: IC3.27 (DB6), IC4.18 (IO6), IC8.18 (IO7); also elsewhere on the board
D7: IC3.26 (DB7), IC4.19 (IO7), IC8.19 (IO8); also elsewhere on the board
GND: C6.1, IC4.14 (GND); also elsewhere on the board
unnamed: IC3.2 (RDY), R4.1
unnamed: IC3.6 (NMI), R6.1
unnamed: IC3.38 (SO), R7.1
PHI2: IC3.39 (PHI2); also elsewhere on the board
R!W: IC3.34 (R/W), IC8.27 (!WE); also elsewhere on the board
VCC: C6.2, IC4.27 (!WE), IC4.28 (VCC), R4.2, R5.2, R6.2, R7.2; also elsewhere on the board

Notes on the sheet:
Dirk Grappendorf
grappendorf.net
CERN Open Hardware License 1.1

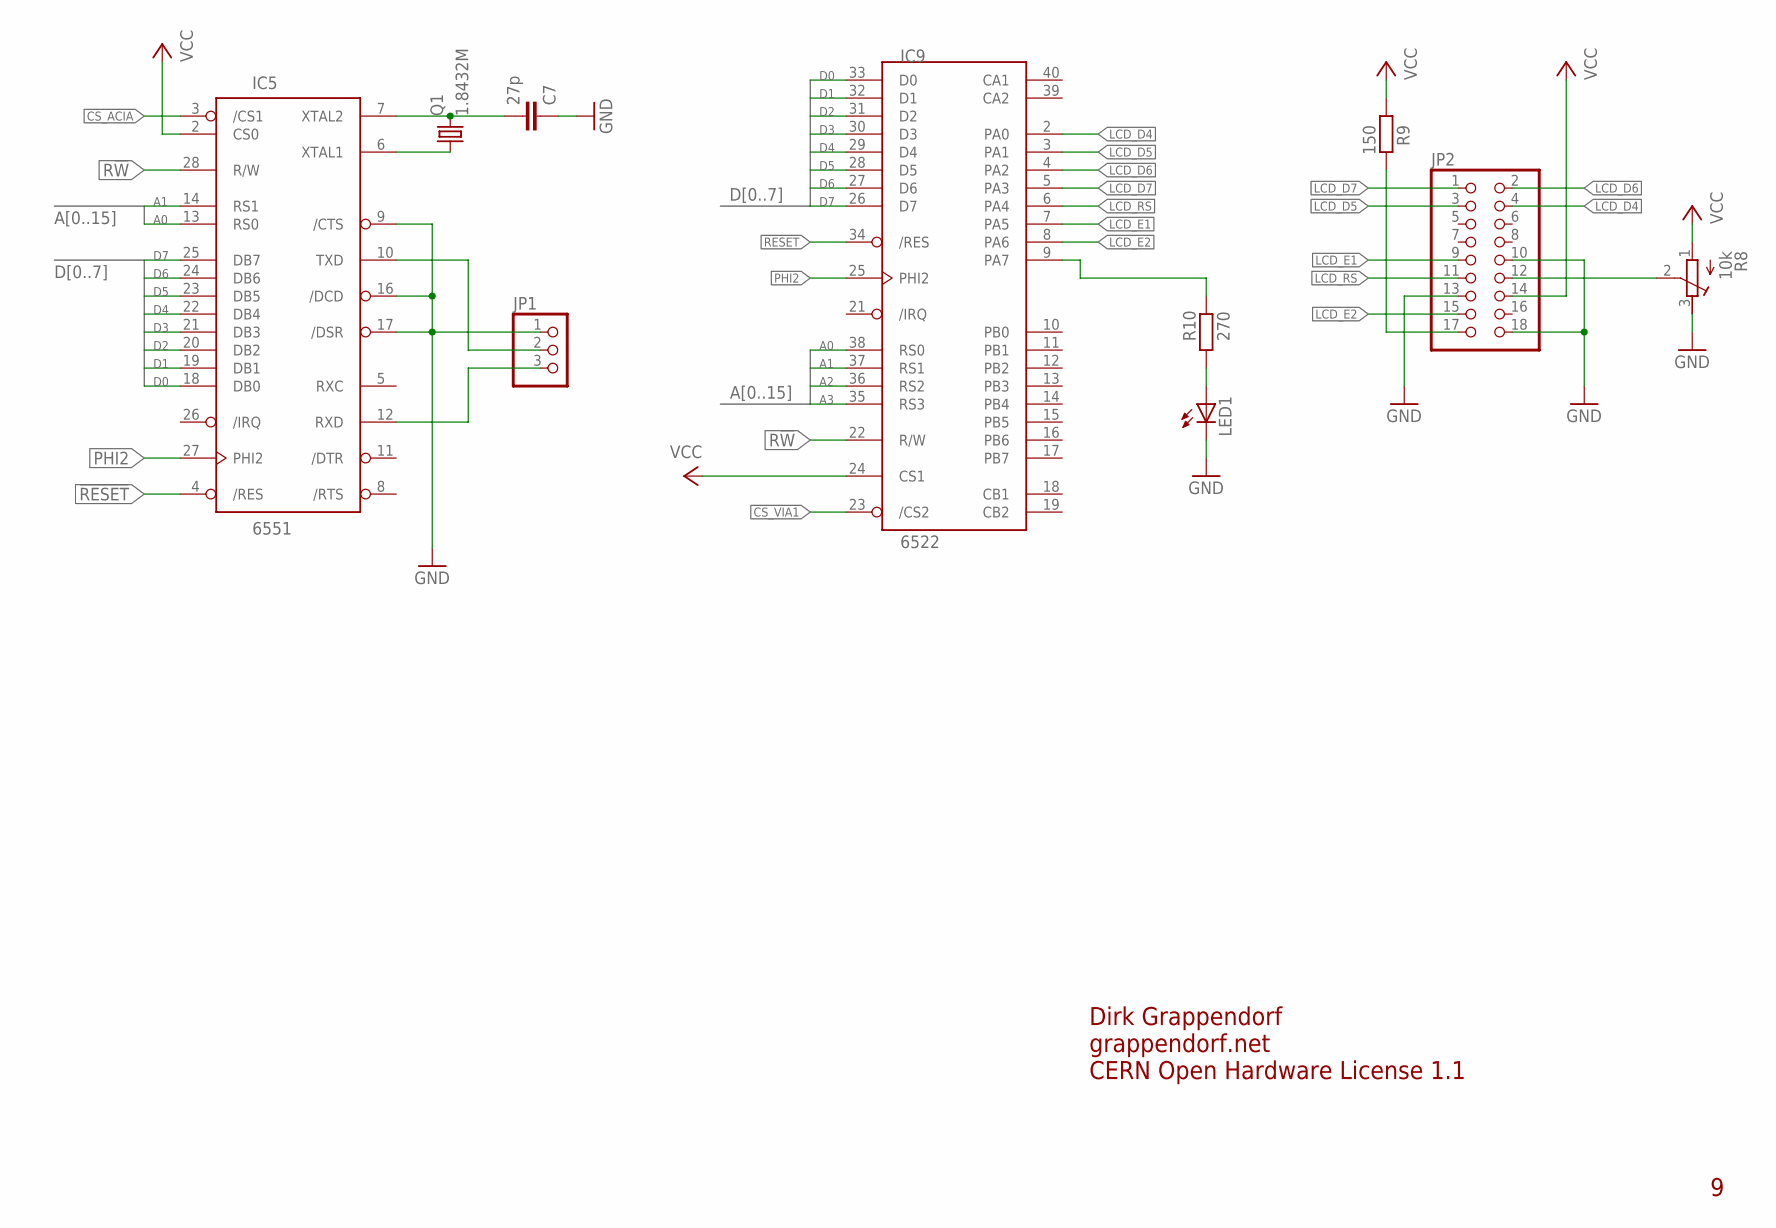
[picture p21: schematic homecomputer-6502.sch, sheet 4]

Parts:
C7: 27p; C025-024X044
IC5: 6551; DIP28
IC9: 6522; DIP40
JP1: PINHD-1X3_2.54; 1X03
JP2: PINHD-2X9_2.54; 2X09
LED1: LED3MM
Q1: 1.8432M; HC49U-V
R8: 10k; RTRIM3339P
R9: 150; 0204/5
R10: 270; 0204/5

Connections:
!CS_ACIA: IC5.3 (/CS1); also elsewhere on the board
!CS_VIA1: IC9.23 (/CS2); also elsewhere on the board
!RESET: IC5.4 (/RES), IC9.34 (/RES); also elsewhere on the board
A0: IC5.13 (RS0), IC9.38 (RS0); also elsewhere on the board
A1: IC5.14 (RS1), IC9.37 (RS1); also elsewhere on the board
A2: IC9.36 (RS2); also elsewhere on the board
A3: IC9.35 (RS3); also elsewhere on the board
D0: IC5.18 (DB0), IC9.33 (D0); also elsewhere on the board
D1: IC5.19 (DB1), IC9.32 (D1); also elsewhere on the board
D2: IC5.20 (DB2), IC9.31 (D2); also elsewhere on the board
D3: IC5.21 (DB3), IC9.30 (D3); also elsewhere on the board
D4: IC5.22 (DB4), IC9.29 (D4); also elsewhere on the board
D5: IC5.23 (DB5), IC9.28 (D5); also elsewhere on the board
D6: IC5.24 (DB6), IC9.27 (D6); also elsewhere on the board
D7: IC5.25 (DB7), IC9.26 (D7); also elsewhere on the board
GND: C7.1, IC5.9 (/CTS), IC5.16 (/DCD), IC5.17 (/DSR), JP1.1, JP2.10, JP2.13, JP2.18, LED1.K (C), R8.3 (E); also elsewhere on the board
LCD_D4: IC9.2 (PA0), JP2.4
LCD_D5: IC9.3 (PA1), JP2.3
LCD_D6: IC9.4 (PA2), JP2.2
LCD_D7: IC9.5 (PA3), JP2.1
LCD_E1: IC9.7 (PA5), JP2.9
LCD_E2: IC9.8 (PA6), JP2.15
LCD_RS: IC9.6 (PA4), JP2.11
unnamed: C7.2, IC5.7 (XTAL2), Q1.2
unnamed: IC5.6 (XTAL1), Q1.1
unnamed: IC5.10 (TXD), JP1.2
unnamed: IC9.9 (PA7), R10.2
unnamed: IC5.12 (RXD), JP1.3
unnamed: JP2.12, R8.2 (S)
unnamed: JP2.17, R9.2
unnamed: LED1.A, R10.1
PHI2: IC5.27 (PHI2), IC9.25 (PHI2); also elsewhere on the board
R!W: IC5.28 (R/W), IC9.22 (R/W); also elsewhere on the board
VCC: IC5.2 (CS0), IC9.24 (CS1), JP2.14, R8.1 (A), R9.1; also elsewhere on the board

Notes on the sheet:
Dirk Grappendorf
grappendorf.net
CERN Open Hardware License 1.1

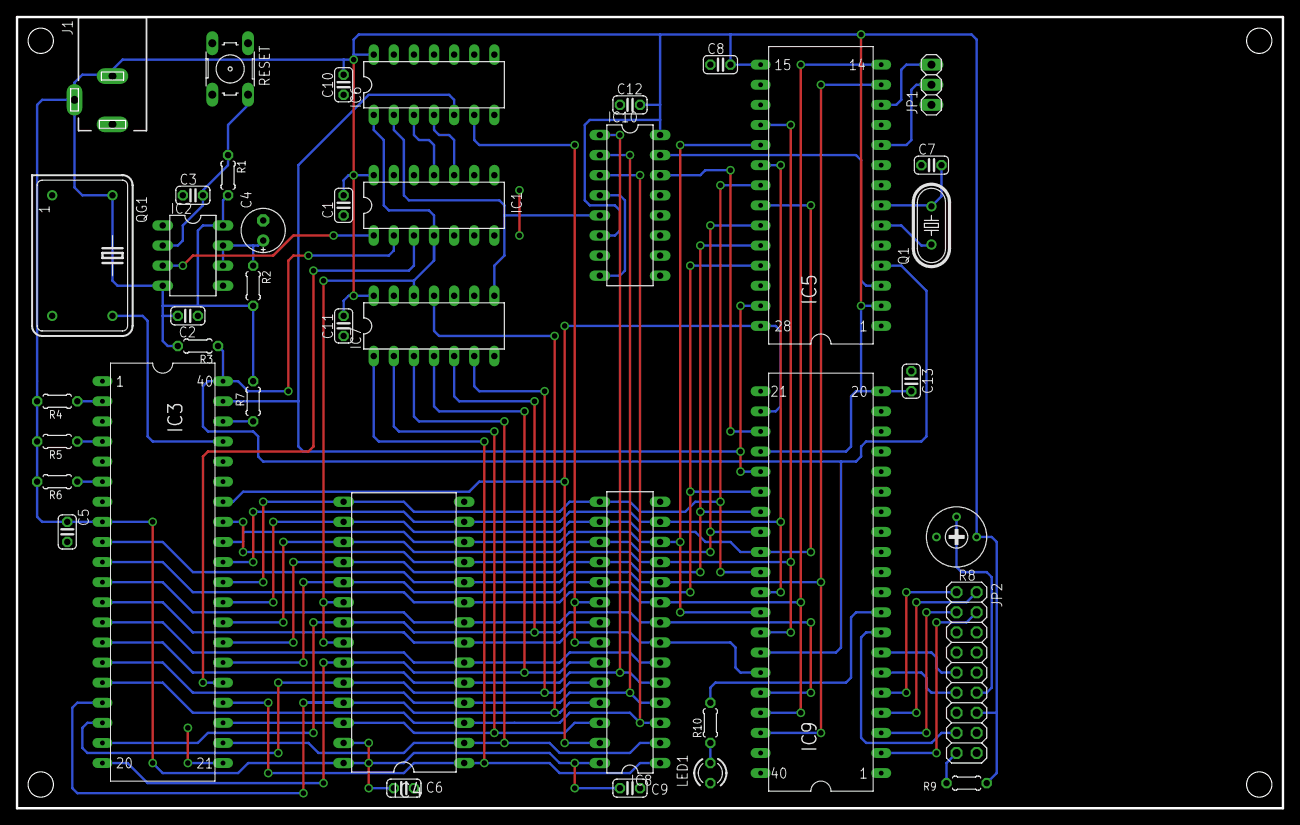
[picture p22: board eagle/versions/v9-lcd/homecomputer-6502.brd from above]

Board: 3 copper layers, 160.0 x 100.0 mm, 40 parts (0 on the bottom side), 59 nets.

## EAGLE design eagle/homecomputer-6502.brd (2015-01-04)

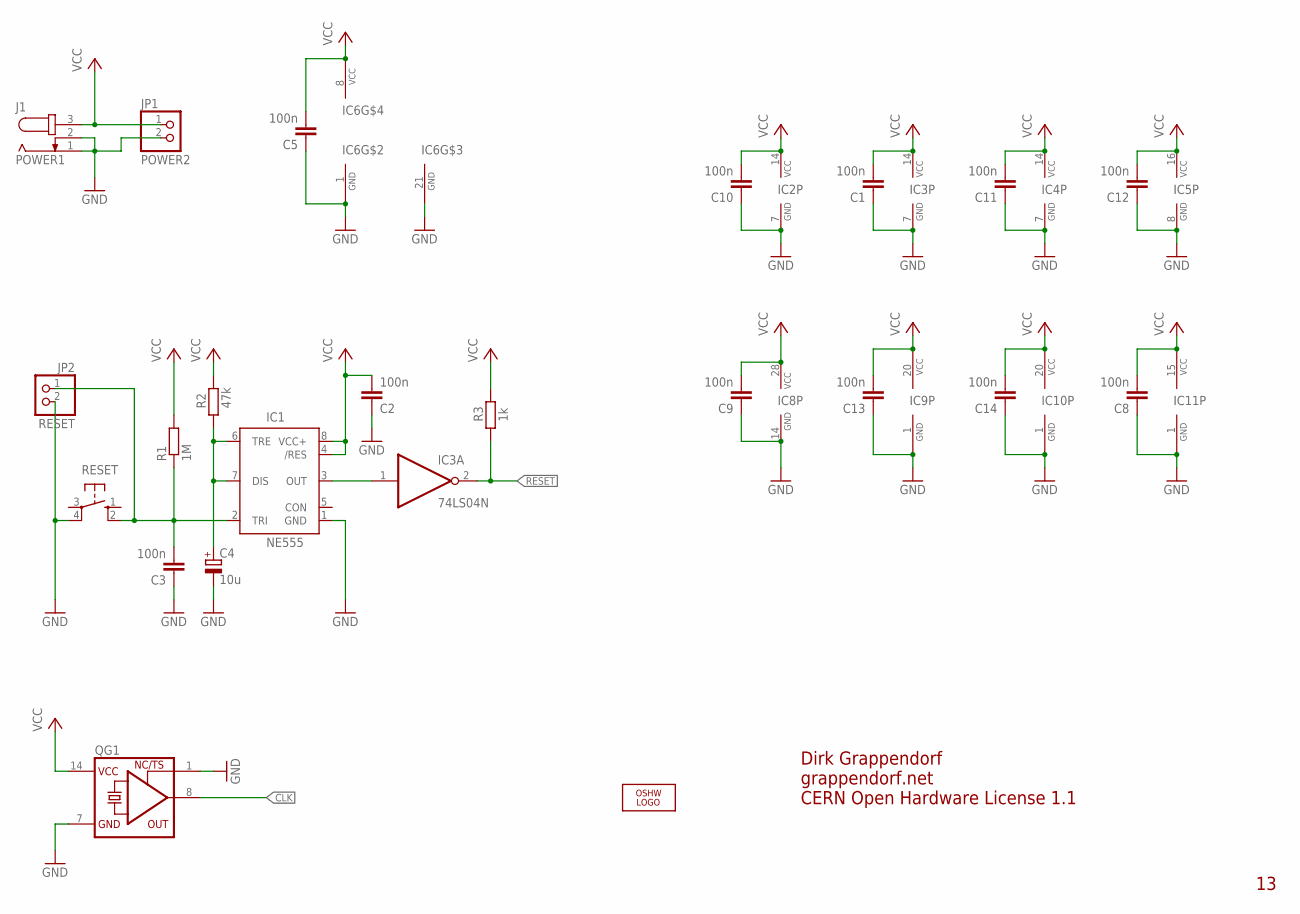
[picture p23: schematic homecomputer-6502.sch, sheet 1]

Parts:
C1, C2, C3, C5, C8, C9, C10, C11, C12, C13, C14: 100n; C025-024X044
C4: 10u; E2,5-6E
IC1: NE555; DIL-08
IC2: 74LS00N; DIL14
IC3: 74LS04N; DIL14
IC4: 74LS30N; DIL14
IC5: 74LS137N; DIL16
IC6: 6502; DIP40
IC8: 61256; DIL28-3
IC9, IC10: 6522; DIP40
IC11: 6551; DIP28
J1: POWER1; SPC4078
JP1: POWER2; 1X02
JP2: RESET; 1X02
LOGO1: OSHW_LOGO_8MILX0350-NT; OSHW_8X350_NOTEXT
QG1: XO-14; DIL14S
R1: 1M; 0204/7
R2: 47k; 0204/7
R3: 1k; 0204/7
RESET: 10-XX; B3F-10XX

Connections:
!RESET: IC3.2 (O), R3.1; also elsewhere on the board
CLK: QG1.8 (OUT); also elsewhere on the board
GND: C1.1, C2.1, C3.1, C4.-, C5.1, C8.1, C9.1, C10.1, C11.1, C12.1, C13.1, C14.1, IC1.1 (GND), IC2.7 (GND), IC3.7 (GND), IC4.7 (GND), IC5.8 (GND), IC6.1 (GND), IC6.21 (GND), IC8.14 (GND), IC9.1 (GND), IC10.1 (GND), IC11.1 (GND), J1.1, J1.2, JP1.2, JP2.2, QG1.1 (TS), QG1.7 (GND), RESET.4 (P1); also elsewhere on the board
unnamed: C4.+, IC1.6 (TRE), IC1.7 (DIS), R2.1
unnamed: IC1.3 (OUT), IC3.1 (I)
unnamed: C3.2, IC1.2 (TRI), JP2.1, R1.1, RESET.2 (S1)
VCC: C1.2, C2.2, C5.2, C8.2, C9.2, C10.2, C11.2, C12.2, C13.2, C14.2, IC1.4 (/RES), IC1.8 (VCC+), IC2.14 (VCC), IC3.14 (VCC), IC4.14 (VCC), IC5.16 (VCC), IC6.8 (VCC), IC8.28 (VCC), IC9.20 (VCC), IC10.20 (VCC), IC11.15 (VCC), J1.3, JP1.1, QG1.14 (VCC), R1.2, R2.2, R3.2; also elsewhere on the board

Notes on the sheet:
Dirk Grappendorf
grappendorf.net
CERN Open Hardware License 1.1

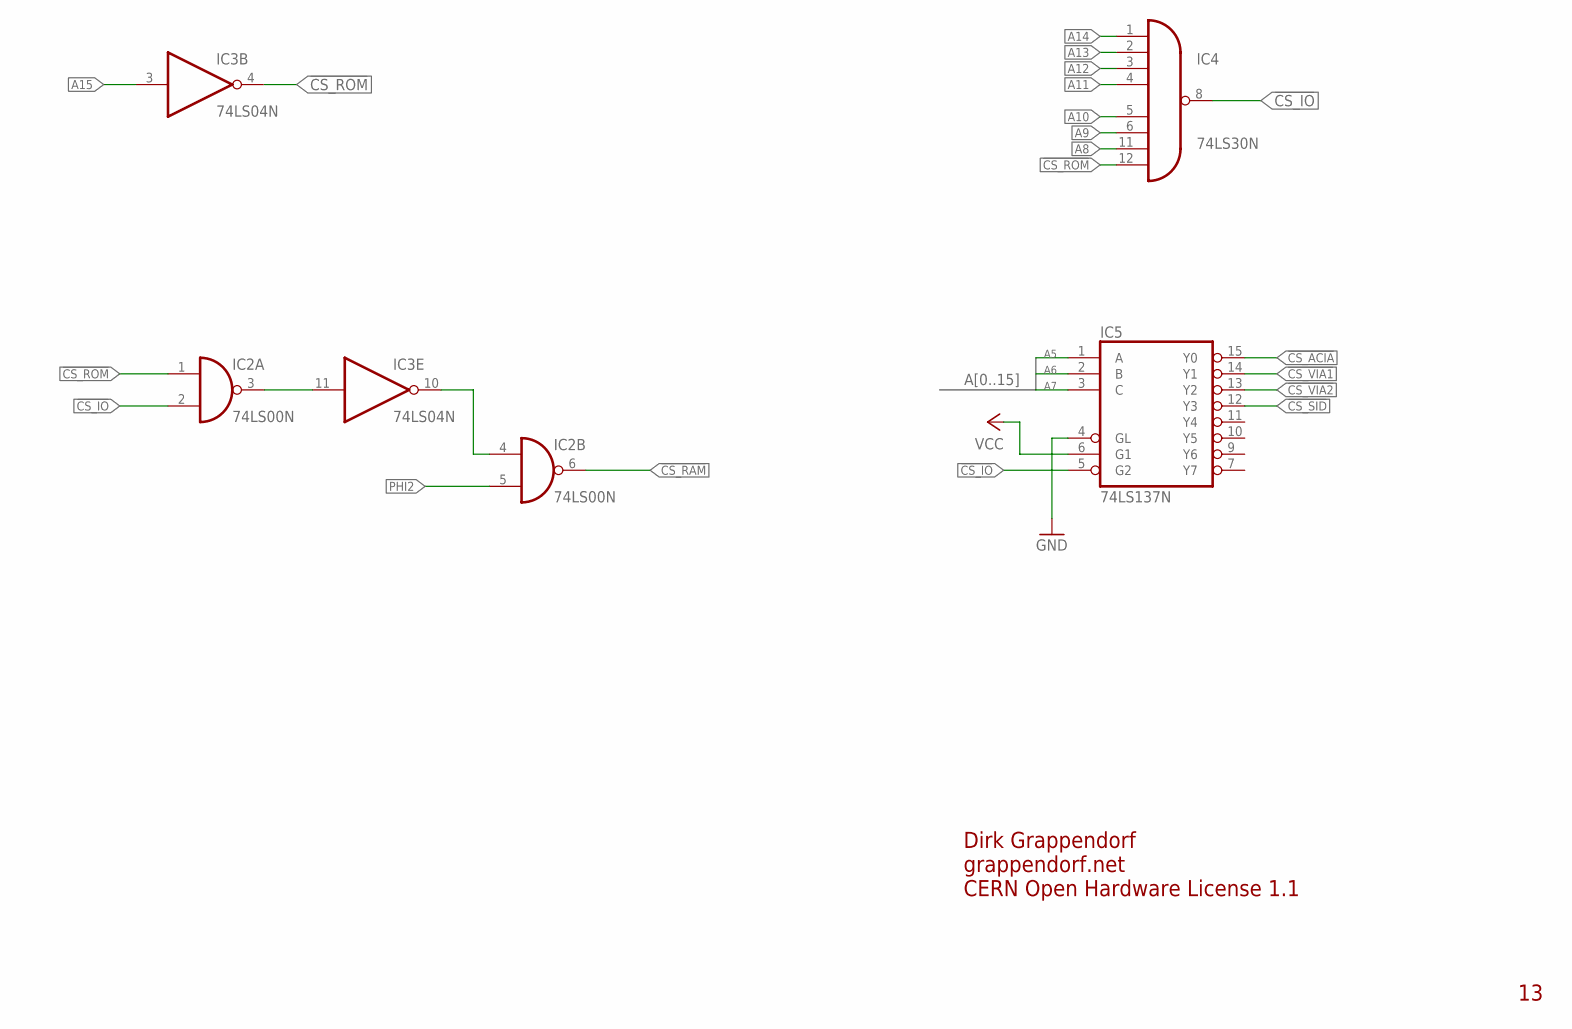
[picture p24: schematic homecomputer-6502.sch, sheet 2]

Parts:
IC2: 74LS00N; DIL14
IC3: 74LS04N; DIL14
IC4: 74LS30N; DIL14
IC5: 74LS137N; DIL16

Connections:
!CS_ACIA: IC5.15 (Y0); also elsewhere on the board
!CS_IO: IC2.2 (I1), IC4.8 (O), IC5.5 (G2)
!CS_RAM: IC2.6 (O); also elsewhere on the board
!CS_ROM: IC2.1 (I0), IC3.4 (O), IC4.12 (I7); also elsewhere on the board
!CS_SID: IC5.12 (Y3); also elsewhere on the board
!CS_VIA1: IC5.14 (Y1); also elsewhere on the board
!CS_VIA2: IC5.13 (Y2); also elsewhere on the board
A5: IC5.1 (A); also elsewhere on the board
A6: IC5.2 (B); also elsewhere on the board
A7: IC5.3 (C); also elsewhere on the board
A8: IC4.11 (I6); also elsewhere on the board
A9: IC4.6 (I5); also elsewhere on the board
A10: IC4.5 (I4); also elsewhere on the board
A11: IC4.4 (I3); also elsewhere on the board
A12: IC4.3 (I2); also elsewhere on the board
A13: IC4.2 (I1); also elsewhere on the board
A14: IC4.1 (I0); also elsewhere on the board
A15: IC3.3 (I); also elsewhere on the board
GND: IC5.4 (GL); also elsewhere on the board
unnamed: IC2.3 (O), IC3.11 (I)
unnamed: IC2.4 (I0), IC3.10 (O)
PHI2: IC2.5 (I1); also elsewhere on the board
VCC: IC5.6 (G1); also elsewhere on the board

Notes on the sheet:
Dirk Grappendorf
grappendorf.net
CERN Open Hardware License 1.1

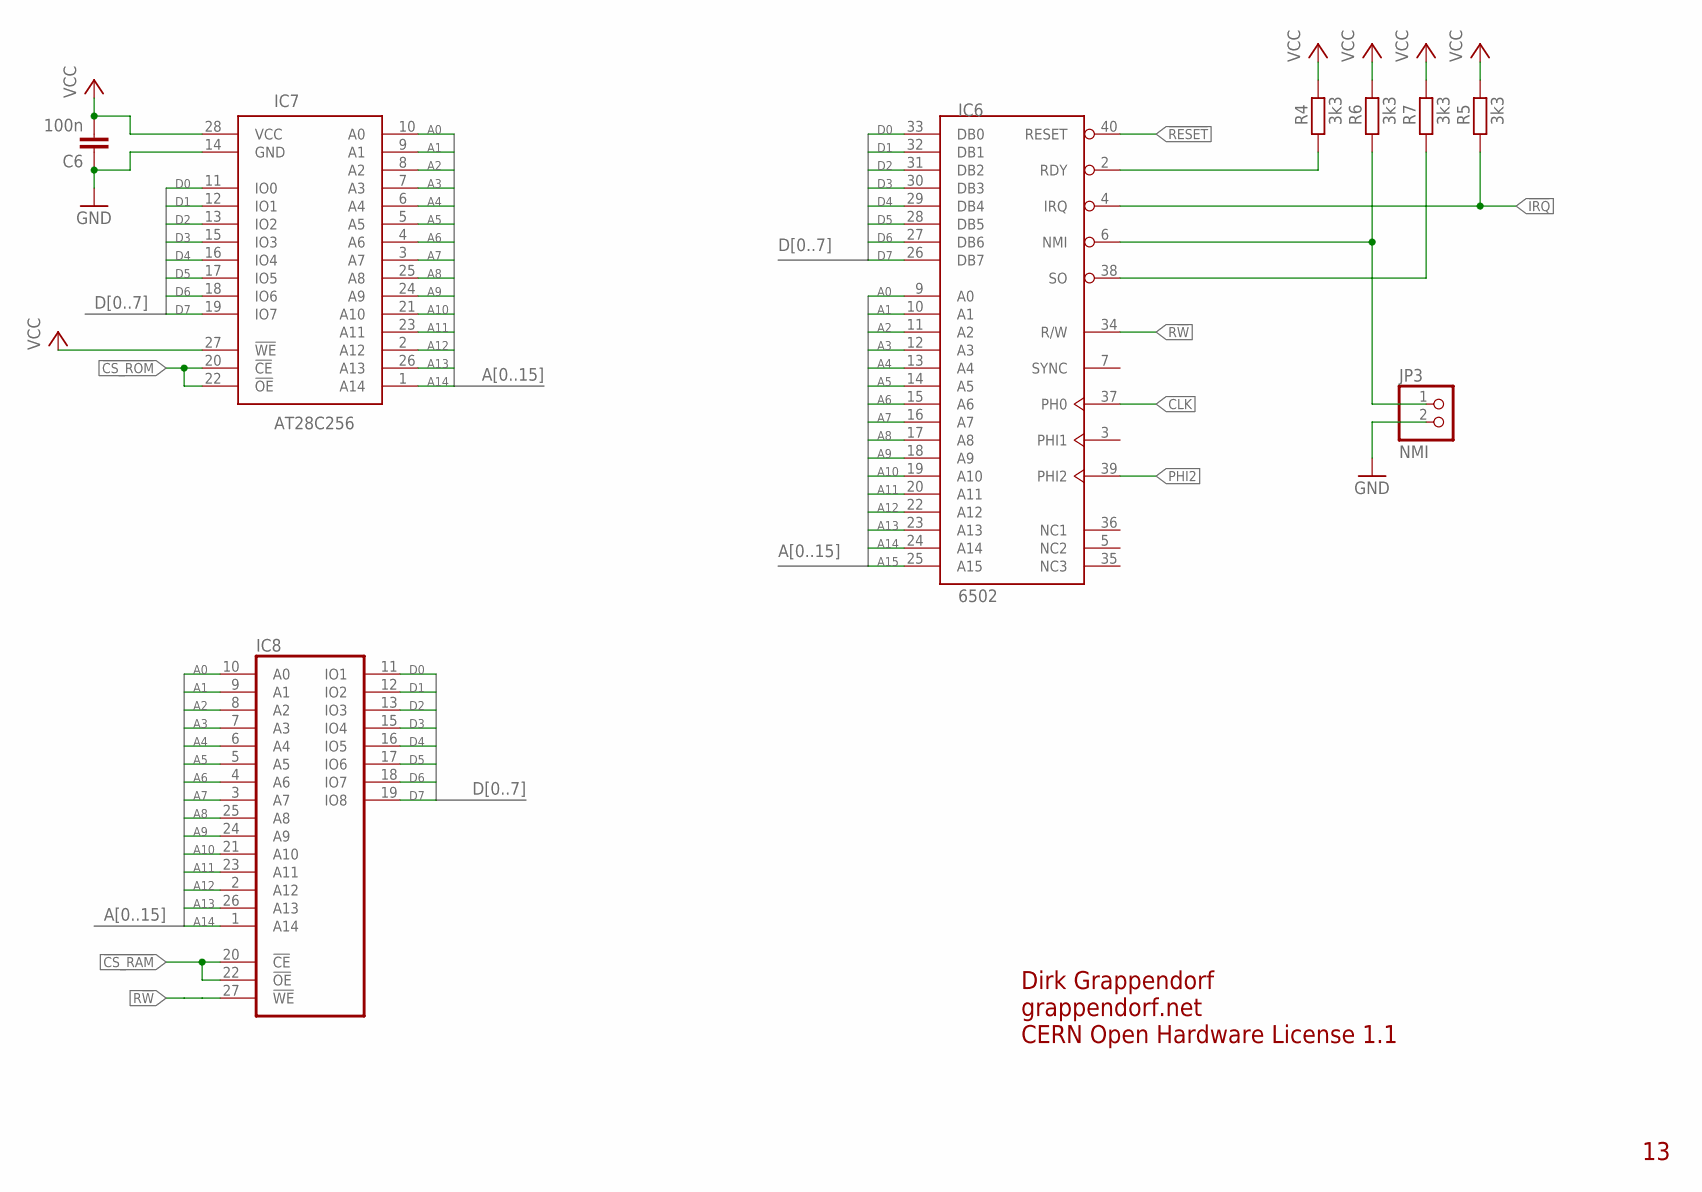
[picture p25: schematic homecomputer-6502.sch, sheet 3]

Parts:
C6: 100n; C025-024X044
IC6: 6502; DIP40
IC7: AT28C256; DIL28-6
IC8: 61256; DIL28-3
JP3: NMI; 1X02
R4, R5, R6, R7: 3k3; 0204/7

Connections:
!CS_RAM: IC8.20 (!CE), IC8.22 (!OE); also elsewhere on the board
!CS_ROM: IC7.20 (!CE), IC7.22 (!OE); also elsewhere on the board
!IRQ: IC6.4 (IRQ), R5.1; also elsewhere on the board
!RESET: IC6.40 (RESET); also elsewhere on the board
A0: IC6.9 (A0), IC7.10 (A0), IC8.10 (A0); also elsewhere on the board
A1: IC6.10 (A1), IC7.9 (A1), IC8.9 (A1); also elsewhere on the board
A2: IC6.11 (A2), IC7.8 (A2), IC8.8 (A2); also elsewhere on the board
A3: IC6.12 (A3), IC7.7 (A3), IC8.7 (A3); also elsewhere on the board
A4: IC6.13 (A4), IC7.6 (A4), IC8.6 (A4); also elsewhere on the board
A5: IC6.14 (A5), IC7.5 (A5), IC8.5 (A5); also elsewhere on the board
A6: IC6.15 (A6), IC7.4 (A6), IC8.4 (A6); also elsewhere on the board
A7: IC6.16 (A7), IC7.3 (A7), IC8.3 (A7); also elsewhere on the board
A8: IC6.17 (A8), IC7.25 (A8), IC8.25 (A8); also elsewhere on the board
A9: IC6.18 (A9), IC7.24 (A9), IC8.24 (A9); also elsewhere on the board
A10: IC6.19 (A10), IC7.21 (A10), IC8.21 (A10); also elsewhere on the board
A11: IC6.20 (A11), IC7.23 (A11), IC8.23 (A11); also elsewhere on the board
A12: IC6.22 (A12), IC7.2 (A12), IC8.2 (A12); also elsewhere on the board
A13: IC6.23 (A13), IC7.26 (A13), IC8.26 (A13); also elsewhere on the board
A14: IC6.24 (A14), IC7.1 (A14), IC8.1 (A14); also elsewhere on the board
A15: IC6.25 (A15); also elsewhere on the board
CLK: IC6.37 (PH0); also elsewhere on the board
D0: IC6.33 (DB0), IC7.11 (IO0), IC8.11 (IO1); also elsewhere on the board
D1: IC6.32 (DB1), IC7.12 (IO1), IC8.12 (IO2); also elsewhere on the board
D2: IC6.31 (DB2), IC7.13 (IO2), IC8.13 (IO3); also elsewhere on the board
D3: IC6.30 (DB3), IC7.15 (IO3), IC8.15 (IO4); also elsewhere on the board
D4: IC6.29 (DB4), IC7.16 (IO4), IC8.16 (IO5); also elsewhere on the board
D5: IC6.28 (DB5), IC7.17 (IO5), IC8.17 (IO6); also elsewhere on the board
D6: IC6.27 (DB6), IC7.18 (IO6), IC8.18 (IO7); also elsewhere on the board
D7: IC6.26 (DB7), IC7.19 (IO7), IC8.19 (IO8); also elsewhere on the board
GND: C6.1, IC7.14 (GND), JP3.2; also elsewhere on the board
unnamed: IC6.2 (RDY), R4.1
unnamed: IC6.6 (NMI), JP3.1, R6.1
unnamed: IC6.38 (SO), R7.1
PHI2: IC6.39 (PHI2); also elsewhere on the board
R!W: IC6.34 (R/W), IC8.27 (!WE); also elsewhere on the board
VCC: C6.2, IC7.27 (!WE), IC7.28 (VCC), R4.2, R5.2, R6.2, R7.2; also elsewhere on the board

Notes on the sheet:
Dirk Grappendorf
grappendorf.net
CERN Open Hardware License 1.1

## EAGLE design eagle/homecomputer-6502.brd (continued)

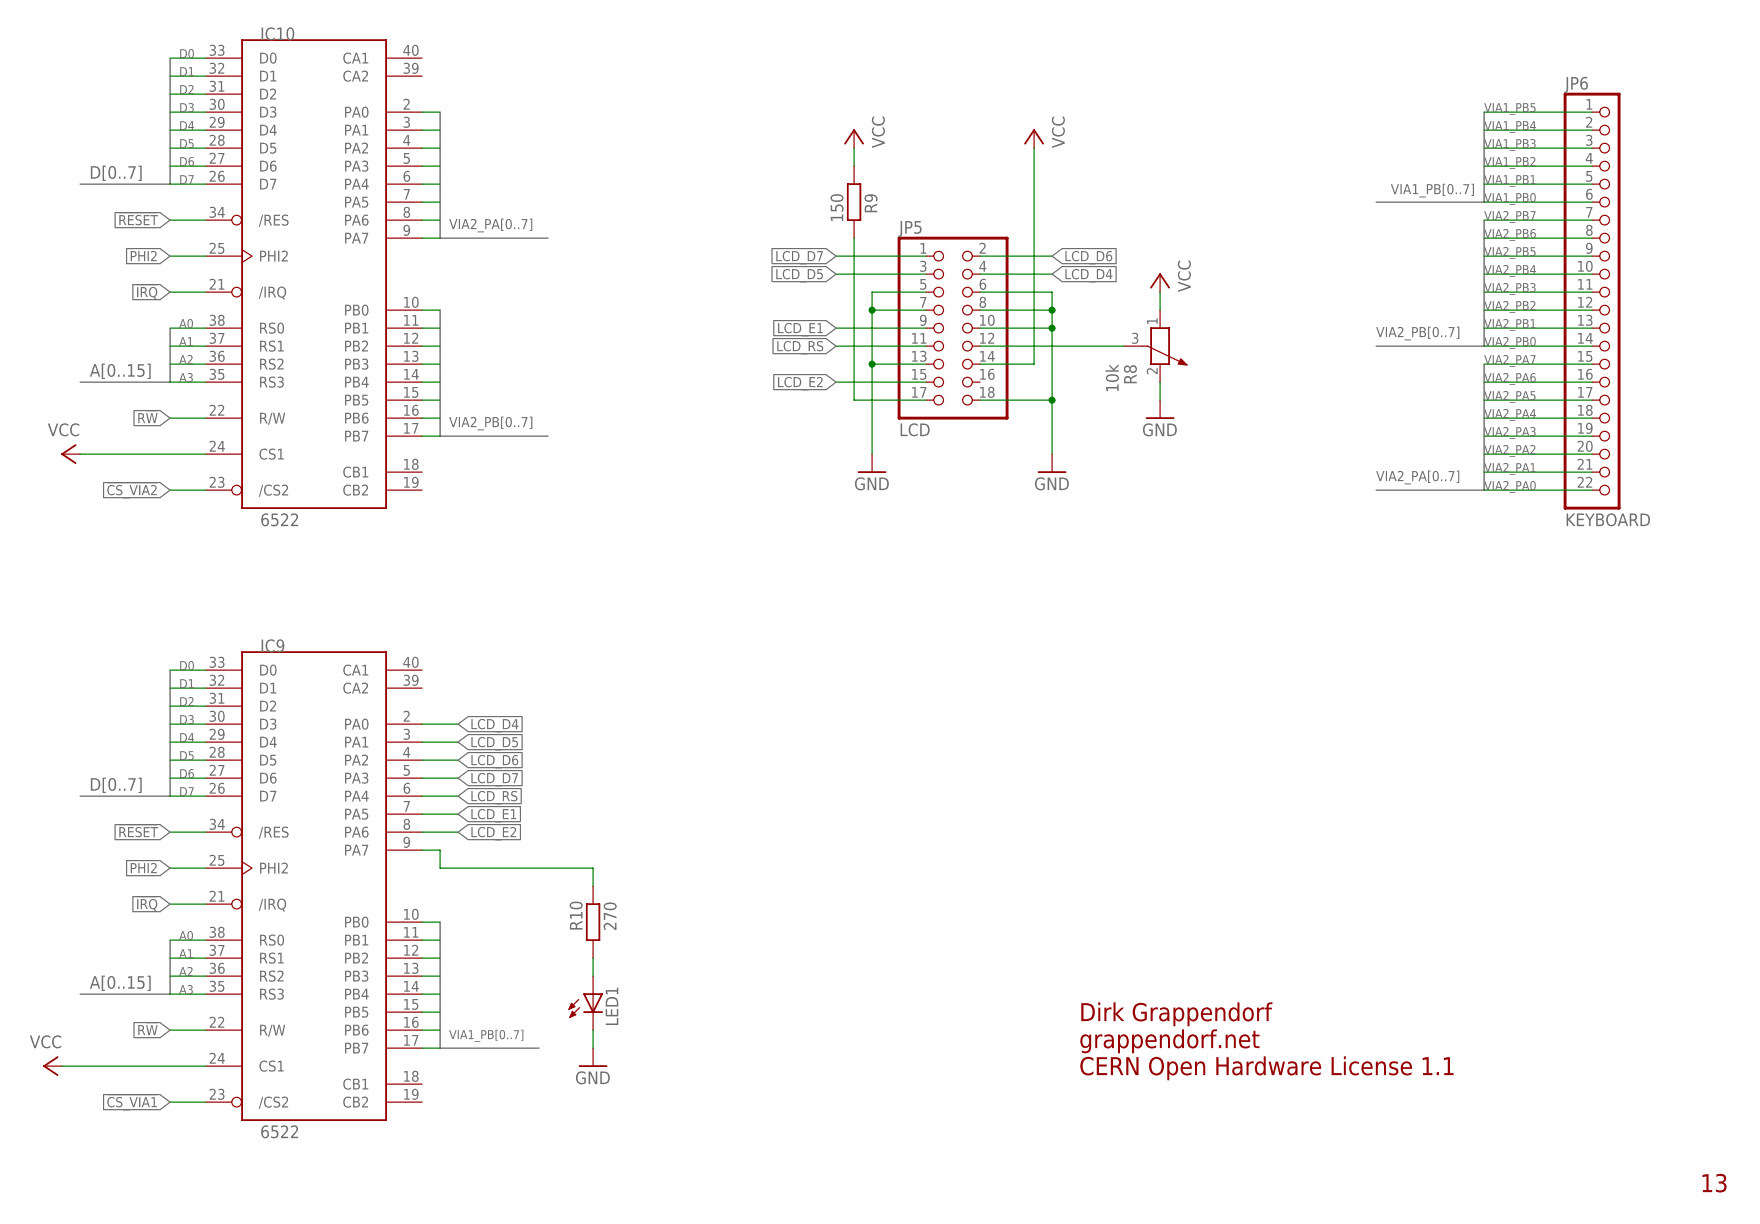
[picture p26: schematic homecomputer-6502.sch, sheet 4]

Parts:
IC9, IC10: 6522; DIP40
JP5: LCD; 2X09
JP6: KEYBOARD; 1X22
LED1: LED3MM
R8: 10k; PT-10
R9: 150; 0204/7
R10: 270; 0204/7

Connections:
!CS_VIA1: IC9.23 (/CS2); also elsewhere on the board
!CS_VIA2: IC10.23 (/CS2); also elsewhere on the board
!IRQ: IC9.21 (/IRQ), IC10.21 (/IRQ); also elsewhere on the board
!RESET: IC9.34 (/RES), IC10.34 (/RES); also elsewhere on the board
A0: IC9.38 (RS0), IC10.38 (RS0); also elsewhere on the board
A1: IC9.37 (RS1), IC10.37 (RS1); also elsewhere on the board
A2: IC9.36 (RS2), IC10.36 (RS2); also elsewhere on the board
A3: IC9.35 (RS3), IC10.35 (RS3); also elsewhere on the board
D0: IC9.33 (D0), IC10.33 (D0); also elsewhere on the board
D1: IC9.32 (D1), IC10.32 (D1); also elsewhere on the board
D2: IC9.31 (D2), IC10.31 (D2); also elsewhere on the board
D3: IC9.30 (D3), IC10.30 (D3); also elsewhere on the board
D4: IC9.29 (D4), IC10.29 (D4); also elsewhere on the board
D5: IC9.28 (D5), IC10.28 (D5); also elsewhere on the board
D6: IC9.27 (D6), IC10.27 (D6); also elsewhere on the board
D7: IC9.26 (D7), IC10.26 (D7); also elsewhere on the board
GND: JP5.5, JP5.6, JP5.7, JP5.8, JP5.10, JP5.13, JP5.18, LED1.K (C), R8.2; also elsewhere on the board
LCD_D4: IC9.2 (PA0), JP5.4
LCD_D5: IC9.3 (PA1), JP5.3
LCD_D6: IC9.4 (PA2), JP5.2
LCD_D7: IC9.5 (PA3), JP5.1
LCD_E1: IC9.7 (PA5), JP5.9
LCD_E2: IC9.8 (PA6), JP5.15
LCD_RS: IC9.6 (PA4), JP5.11
unnamed: IC9.9 (PA7), R10.2
unnamed: JP5.12, R8.3
unnamed: JP5.17, R9.2
unnamed: LED1.A, R10.1
PHI2: IC9.25 (PHI2), IC10.25 (PHI2); also elsewhere on the board
R!W: IC9.22 (R/W), IC10.22 (R/W); also elsewhere on the board
VCC: IC9.24 (CS1), IC10.24 (CS1), JP5.14, R8.1, R9.1; also elsewhere on the board
VIA1_PB0: IC9.10 (PB0), JP6.6
VIA1_PB1: IC9.11 (PB1), JP6.5
VIA1_PB2: IC9.12 (PB2), JP6.4
VIA1_PB3: IC9.13 (PB3), JP6.3
VIA1_PB4: IC9.14 (PB4), JP6.2
VIA1_PB5: IC9.15 (PB5), JP6.1
VIA1_PB6: IC9.16 (PB6)
VIA1_PB7: IC9.17 (PB7)
VIA2_PA0: IC10.2 (PA0), JP6.22
VIA2_PA1: IC10.3 (PA1), JP6.21
VIA2_PA2: IC10.4 (PA2), JP6.20
VIA2_PA3: IC10.5 (PA3), JP6.19
VIA2_PA4: IC10.6 (PA4), JP6.18
VIA2_PA5: IC10.7 (PA5), JP6.17
VIA2_PA6: IC10.8 (PA6), JP6.16
VIA2_PA7: IC10.9 (PA7), JP6.15
VIA2_PB0: IC10.10 (PB0), JP6.14
VIA2_PB1: IC10.11 (PB1), JP6.13
VIA2_PB2: IC10.12 (PB2), JP6.12
VIA2_PB3: IC10.13 (PB3), JP6.11
VIA2_PB4: IC10.14 (PB4), JP6.10
VIA2_PB5: IC10.15 (PB5), JP6.9
VIA2_PB6: IC10.16 (PB6), JP6.8
VIA2_PB7: IC10.17 (PB7), JP6.7

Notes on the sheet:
Dirk Grappendorf
grappendorf.net
CERN Open Hardware License 1.1

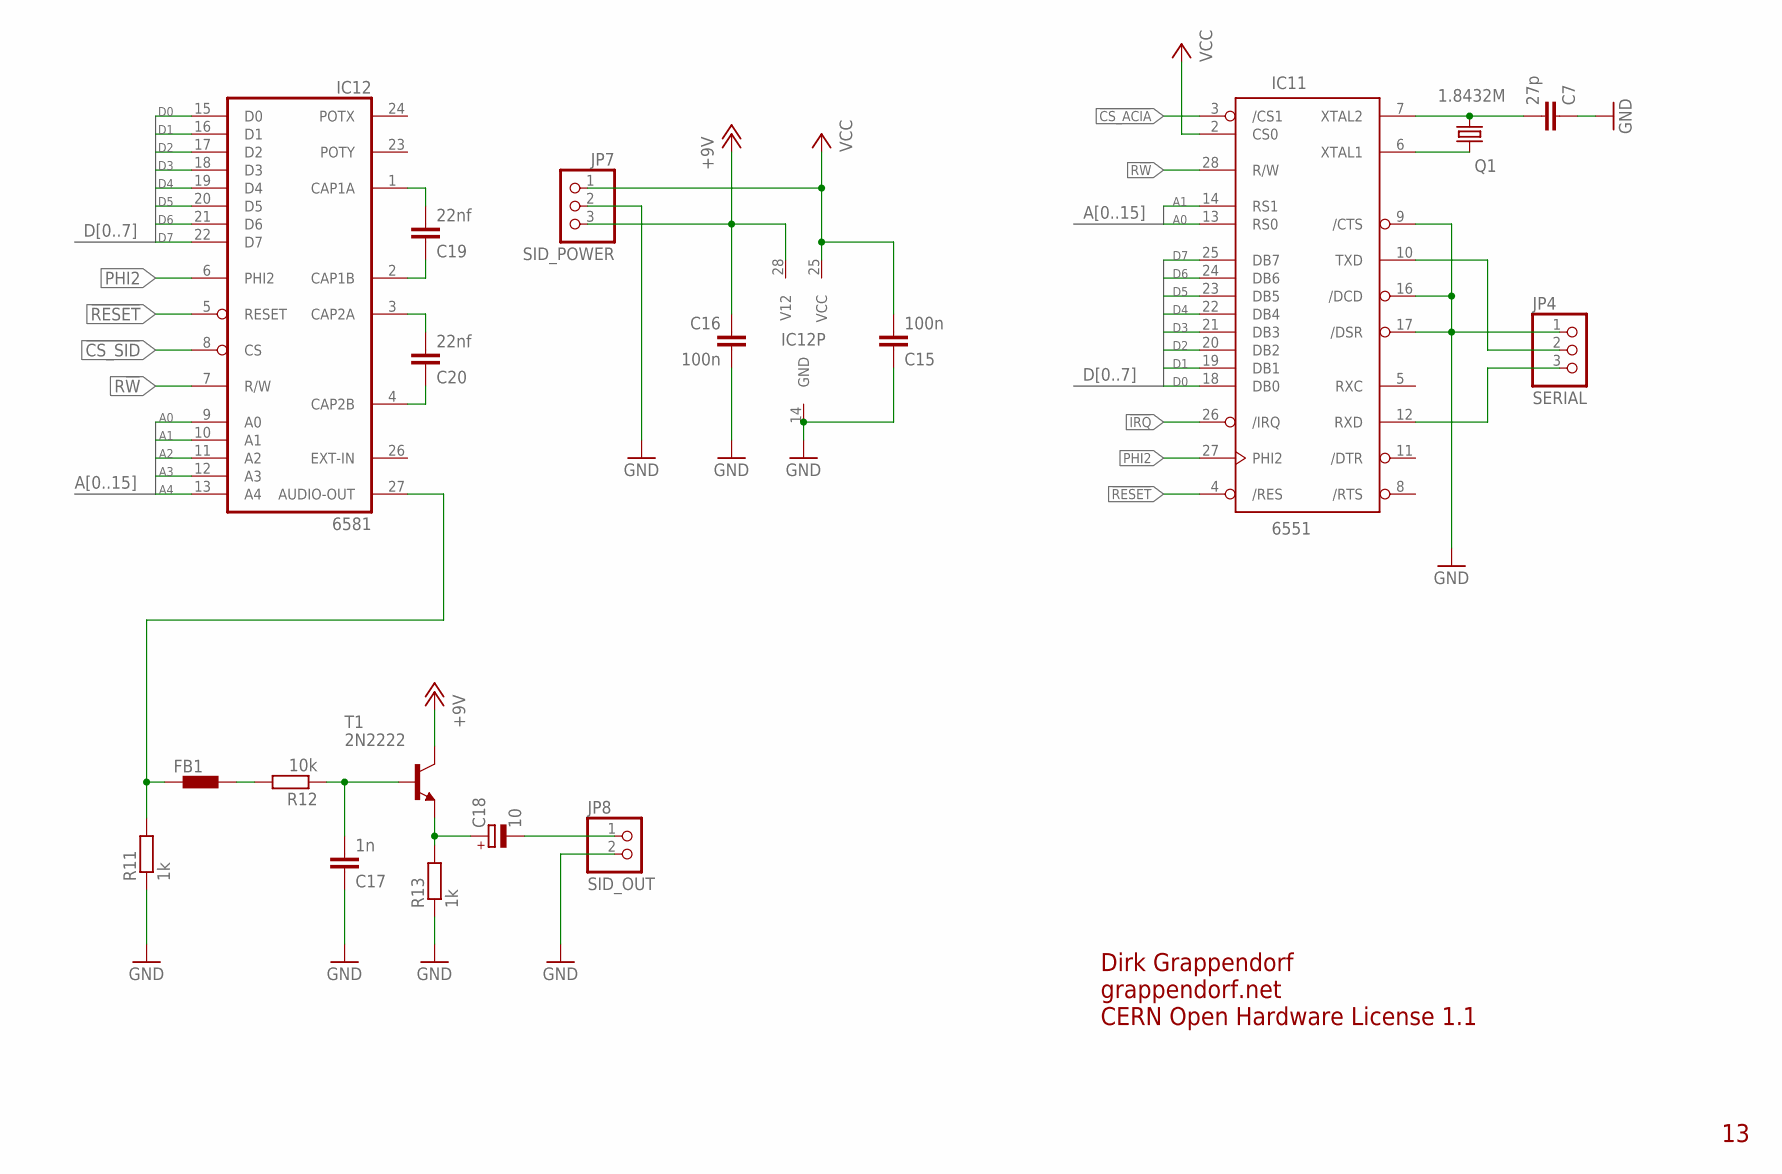
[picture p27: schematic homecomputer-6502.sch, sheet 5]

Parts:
C7: 27p; C025-024X044
C15, C16: 100n; C025-024X044
C17: 1n; C025-024X044
C18: 10; E2,5-5
C19, C20: 22nf; C025-024X044
FB1: BL01RN1A
IC11: 6551; DIP28
IC12: 6581; DIL28
JP4: SERIAL; 1X03
JP7: SID_POWER; 1X03
JP8: SID_OUT; 1X02
Q1: 1.8432M; HC49U-V
R11: 1k; 0204/7
R12: 10k; 0204/7
R13: 1k; 0204/5
T1: 2N2222; TO18

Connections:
!CS_ACIA: IC11.3 (/CS1); also elsewhere on the board
!CS_SID: IC12.8 (CS); also elsewhere on the board
!IRQ: IC11.26 (/IRQ); also elsewhere on the board
!RESET: IC11.4 (/RES), IC12.5 (RESET); also elsewhere on the board
+12V: C16.1, IC12.28 (V12), JP7.3, T1.3 (C)
A0: IC11.13 (RS0), IC12.9 (A0); also elsewhere on the board
A1: IC11.14 (RS1), IC12.10 (A1); also elsewhere on the board
A2: IC12.11 (A2); also elsewhere on the board
A3: IC12.12 (A3); also elsewhere on the board
A4: IC12.13 (A4); also elsewhere on the board
D0: IC11.18 (DB0), IC12.15 (D0); also elsewhere on the board
D1: IC11.19 (DB1), IC12.16 (D1); also elsewhere on the board
D2: IC11.20 (DB2), IC12.17 (D2); also elsewhere on the board
D3: IC11.21 (DB3), IC12.18 (D3); also elsewhere on the board
D4: IC11.22 (DB4), IC12.19 (D4); also elsewhere on the board
D5: IC11.23 (DB5), IC12.20 (D5); also elsewhere on the board
D6: IC11.24 (DB6), IC12.21 (D6); also elsewhere on the board
D7: IC11.25 (DB7), IC12.22 (D7); also elsewhere on the board
GND: C7.1, C15.1, C16.2, C17.1, IC11.9 (/CTS), IC11.16 (/DCD), IC11.17 (/DSR), IC12.14 (GND), JP4.1, JP7.2, JP8.2, R11.1, R13.1; also elsewhere on the board
unnamed: C7.2, IC11.7 (XTAL2), Q1.2
unnamed: IC11.6 (XTAL1), Q1.1
unnamed: IC11.10 (TXD), JP4.2
unnamed: IC11.12 (RXD), JP4.3
unnamed: FB1.1, IC12.27 (AUDIO-OUT), R11.2
unnamed: C19.2, IC12.1 (CAP1A)
unnamed: FB1.2, R12.2
unnamed: C17.2, R12.1, T1.2 (B)
unnamed: C18.+, R13.2, T1.1 (E)
unnamed: C18.-, JP8.1
unnamed: C19.1, IC12.2 (CAP1B)
unnamed: C20.2, IC12.3 (CAP2A)
unnamed: C20.1, IC12.4 (CAP2B)
PHI2: IC11.27 (PHI2), IC12.6 (PHI2); also elsewhere on the board
R!W: IC11.28 (R/W), IC12.7 (R/W); also elsewhere on the board
VCC: C15.2, IC11.2 (CS0), IC12.25 (VCC), JP7.1; also elsewhere on the board

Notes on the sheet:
Dirk Grappendorf
grappendorf.net
CERN Open Hardware License 1.1

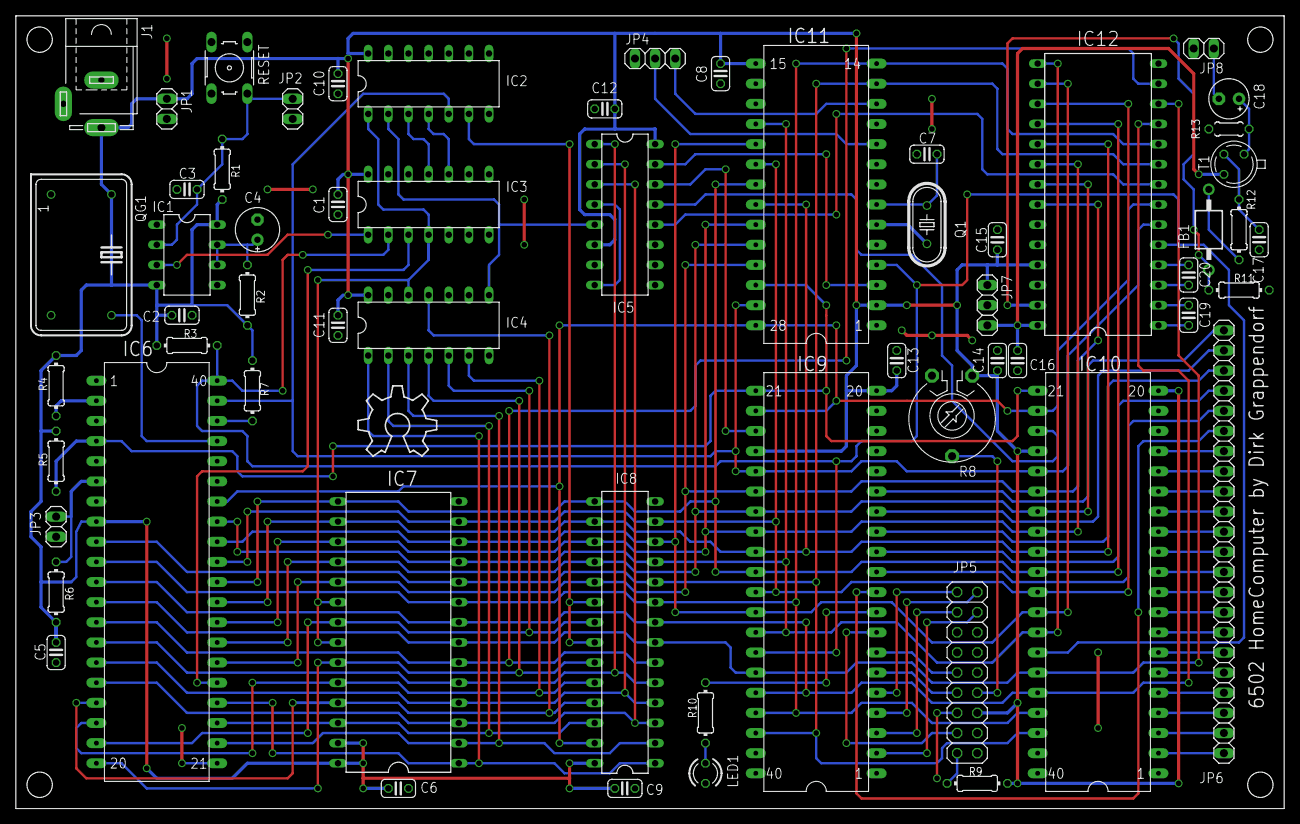
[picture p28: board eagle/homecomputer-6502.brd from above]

Board: 2 copper layers, 160.0 x 100.0 mm, 61 parts (0 on the bottom side), 93 nets.

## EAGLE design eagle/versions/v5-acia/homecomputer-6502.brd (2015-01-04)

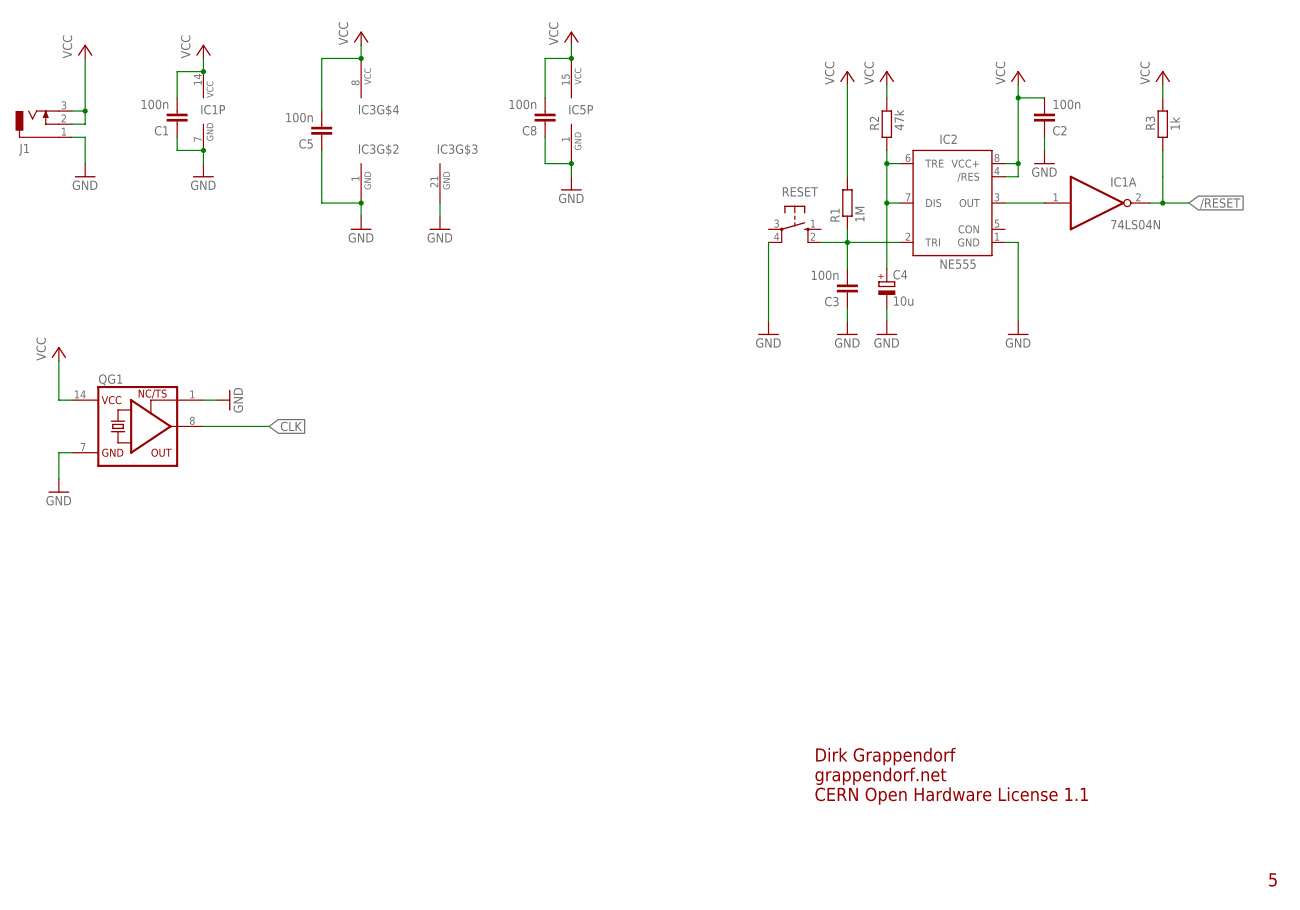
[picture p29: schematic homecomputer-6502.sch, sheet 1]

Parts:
C1, C2, C3, C5, C8: 100n; C025-024X044
C4: 10u; E2,5-6E
IC1: 74LS04N; DIL14
IC2: NE555; DIL-08
IC3: 6502; DIP40
IC5: 6551; DIP28
J1: DCJ0303
QG1: XO-14; DIL14S
R1: 1M; 0204/5
R2: 47k; 0204/5
R3: 1k; 0204/5
RESET: 10-XX; B3F-10XX

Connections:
/RESET: IC1.2 (O), R3.1; also elsewhere on the board
CLK: QG1.8 (OUT); also elsewhere on the board
GND: C1.1, C2.1, C3.1, C4.-, C5.1, C8.1, IC1.7 (GND), IC2.1 (GND), IC3.1 (GND), IC3.21 (GND), IC5.1 (GND), J1.1, QG1.1 (TS), QG1.7 (GND), RESET.4 (P1); also elsewhere on the board
unnamed: C4.+, IC2.6 (TRE), IC2.7 (DIS), R2.1
unnamed: IC1.1 (I), IC2.3 (OUT)
unnamed: C3.2, IC2.2 (TRI), R1.1, RESET.2 (S1)
VCC: C1.2, C2.2, C5.2, C8.2, IC1.14 (VCC), IC2.4 (/RES), IC2.8 (VCC+), IC3.8 (VCC), IC5.15 (VCC), J1.2, J1.3, QG1.14 (VCC), R1.2, R2.2, R3.2; also elsewhere on the board

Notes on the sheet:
Dirk Grappendorf
grappendorf.net
CERN Open Hardware License 1.1


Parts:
C6: 100n; C025-024X044
C7: 27p; C025-024X044
IC1: 74LS04N; DIL14
IC3: 6502; DIP40
IC4: AT28C256; DIL28-6
IC5: 6551; DIP28
JP1: PINHD-1X3_2.54; 1X03
Q1: 1.8432M; HC49U-V
R4, R5, R6, R7: 3k3; 0204/5

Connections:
/CS_ROM: IC1.4 (O), IC4.20 (!CE), IC4.22 (!OE)
/RESET: IC3.40 (RESET), IC5.4 (/RES); also elsewhere on the board
/WR: IC3.34 (R/W), IC5.28 (R/W)
A0: IC3.9 (A0), IC4.10 (A0), IC5.13 (RS0)
A1: IC3.10 (A1), IC4.9 (A1), IC5.14 (RS1)
A2: IC3.11 (A2), IC4.8 (A2)
A3: IC3.12 (A3), IC4.7 (A3)
A4: IC3.13 (A4), IC4.6 (A4)
A5: IC3.14 (A5), IC4.5 (A5)
A6: IC3.15 (A6), IC4.4 (A6)
A7: IC3.16 (A7), IC4.3 (A7)
A8: IC3.17 (A8), IC4.25 (A8)
A9: IC3.18 (A9), IC4.24 (A9)
A10: IC3.19 (A10), IC4.21 (A10)
A11: IC3.20 (A11), IC4.23 (A11)
A12: IC3.22 (A12), IC4.2 (A12)
A13: IC3.23 (A13), IC4.26 (A13)
A14: IC3.24 (A14), IC4.1 (A14)
A15: IC1.3 (I), IC3.25 (A15), IC5.3 (/CS1)
CLK: IC3.37 (PH0); also elsewhere on the board
D0: IC3.33 (DB0), IC4.11 (IO0), IC5.18 (DB0)
D1: IC3.32 (DB1), IC4.12 (IO1), IC5.19 (DB1)
D2: IC3.31 (DB2), IC4.13 (IO2), IC5.20 (DB2)
D3: IC3.30 (DB3), IC4.15 (IO3), IC5.21 (DB3)
D4: IC3.29 (DB4), IC4.16 (IO4), IC5.22 (DB4)
D5: IC3.28 (DB5), IC4.17 (IO5), IC5.23 (DB5)
D6: IC3.27 (DB6), IC4.18 (IO6), IC5.24 (DB6)
D7: IC3.26 (DB7), IC4.19 (IO7), IC5.25 (DB7)
GND: C6.1, C7.1, IC4.14 (GND), IC5.9 (/CTS), IC5.16 (/DCD), IC5.17 (/DSR), JP1.1; also elsewhere on the board
unnamed: C7.2, IC5.7 (XTAL2), Q1.2
unnamed: IC5.6 (XTAL1), Q1.1
unnamed: IC3.2 (RDY), R4.1
unnamed: IC5.10 (TXD), JP1.2
unnamed: IC3.4 (IRQ), R5.1
unnamed: IC3.6 (NMI), R6.1
unnamed: IC3.38 (SO), R7.1
unnamed: IC5.12 (RXD), JP1.3
PHI2: IC3.39 (PHI2), IC5.27 (PHI2)
VCC: C6.2, IC4.27 (!WE), IC4.28 (VCC), IC5.2 (CS0), R4.2, R5.2, R6.2, R7.2; also elsewhere on the board

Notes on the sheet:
Dirk Grappendorf
grappendorf.net
CERN Open Hardware License 1.1


Board: 3 copper layers, 160.0 x 100.0 mm, 25 parts (0 on the bottom side), 42 nets.

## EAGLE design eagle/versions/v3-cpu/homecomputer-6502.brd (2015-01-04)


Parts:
3K3: 3kl3; 0204/5
/RESET: TPPAD1-13; P1-13
C1: 10n; C025-024X044
C2, C3, C4, C6: 100n; C025-024X044
C5: 10u; E2,5-6E
CLK: TPPAD1-13; P1-13
IC1: 74LS04N; DIL14
IC2: NE555; DIL-08
IC3: 6502; DIP40
J1: DCJ0303
Q1: 1MHz; HC49U-V
R1, R2, R5: 1k; 0204/5
R3: 1M; 0204/5
R4: 47k; 0204/5
R6, R7, R8: 3k3; 0204/5
RESET: 10-XX; B3F-10XX

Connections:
/RESET: /RESET.TP, IC1.8 (O), IC3.40 (RESET), R5.1
CLK: CLK.TP, IC1.6 (O), IC3.37 (PH0)
GND: C2.1, C3.1, C4.1, C5.-, C6.1, IC1.7 (GND), IC2.1 (GND), IC3.1 (GND), IC3.21 (GND), IC3.29 (DB4), IC3.31 (DB2), IC3.33 (DB0), J1.1, RESET.4 (P1)
unnamed: IC1.1 (I), Q1.1, R1.1
unnamed: C1.1, IC1.2 (O), R1.2
unnamed: IC3.2 (RDY), R6.1
unnamed: C5.+, IC2.6 (TRE), IC2.7 (DIS), R4.1
unnamed: IC1.9 (I), IC2.3 (OUT)
unnamed: C4.2, IC2.2 (TRI), R3.1, RESET.2 (S1)
unnamed: C1.2, IC1.3 (I), R2.2
unnamed: IC1.4 (O), IC1.5 (I), Q1.2, R2.1
unnamed: 3K3.1, IC3.4 (IRQ)
unnamed: IC3.6 (NMI), R8.1
unnamed: IC3.38 (SO), R7.1
VCC: 3K3.2, C2.2, C3.2, C6.2, IC1.14 (VCC), IC2.4 (/RES), IC2.8 (VCC+), IC3.8 (VCC), IC3.26 (DB7), IC3.27 (DB6), IC3.28 (DB5), IC3.30 (DB3), IC3.32 (DB1), J1.2, J1.3, R3.2, R4.2, R5.2, R6.2, R7.2, R8.2

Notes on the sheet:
Dirk Grappendorf
grappendorf.net
CERN Open Hardware License 1.1



Board: 2 copper layers, 160.0 x 100.0 mm, 23 parts (2 on the bottom side), 15 nets.

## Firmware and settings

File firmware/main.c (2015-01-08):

#include <stdio.h>
#include <stdlib.h>
#include "acia.h"
#include "keys.h"
#include "led.h"
#include "lcd.h"
#include "basic.h"
#include "readline.h"

int main() {

  acia_init();
  lcd_init();
  led_init();
  keys_init();
  basic_init();

  acia_puts("6502 HomeComputer ready.\n");
  lcd_puts("6502 HomeComputer ready!\n");
  sprintf(print_buffer, "%u bytes free.\n", _heapmemavail());
  lcd_puts(print_buffer);
  lcd_puts("Ready.\n");
  lcd_cursor_on();
  lcd_cursor_blink();

  for (;;) {
    char * line = readline(NON_INTERRUPTIBLE);
    interpret(line);
  }

  return 0;
}

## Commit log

2015-01-04 Add variables: LET sets a variable, VARS lists all variables, CLEAR clears all variables and PRINT can print a variable.
2015-01-04 Add command PRINTLN which prints with newline. Now PRINT prints without newline.
2015-01-04 Add new command INPUT which reads keyboard input into a variable. More verbose print for the SAVE command.
2015-01-06 Rename command PRINTLN to PRINT and PRINT to PUT
2015-01-06 Filter invalid UTF-8 chars that can accidentially arrive on the serial interface
2015-01-07 The RUN command can now be interrupted (NMI) The LIST command can now be interrupted (NMI) and waits for a key press after each line The DIR command can now be interrupted (NMI) and waits for a key p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
2015-01-07 The SLEEP command can now be interrupted (NMI)
2015-01-08 Add builtin variables Add builtin variable ti$ that returns the current time ("hh:mm:ss") Add builtin variable ti that returns the current time in milliseconds Remove commands TIME and UPTIME The VAR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
    [main.c]
2015-01-08 Enable the cursor when a program was interrupted
2015-01-08 Refactor: Add function prototypes, reorder, add commentation
2015-01-08 Allow assignment of integer constants and integer variables to an integer variable Allow assignment of string constants and string variables to a string variable Refactor number/string expression par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
2015-01-08 Allow +-*/ in number expressions (currently without precendence)
2015-01-08 Allow a comma separated list of arguments in the PRINT/PUT command
2015-01-08 Add number comparison operator == Fix: Terminate PRINT/PUT command when an error occourred
2015-01-09 Improve readline navigation: Cursor left/right, Home/Ctrl-A, End/Ctrl-E Insert, Delete, Backspace at any point
2015-01-10 Add new command WRITE that writes a character to the screen but does not move the cursor Use random function from the CC65 standard library Only print "Ready." messages when not running a program
2015-01-10 AT command can now read a character from the screen (AT x,y,var$) Add game of life BASIC program (currently not working because we don't have arrays)
2015-01-26 Add final schematics
    [homecomputer-6502.sch]
